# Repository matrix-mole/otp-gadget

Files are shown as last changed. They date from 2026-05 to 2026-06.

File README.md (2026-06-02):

# OTP Gadget

A handheld, air-gapped device for exchanging encrypted messages with a one-time pad. No radio, no network, no cloud. Two devices, one MicroSD card swap, then messages flow by QR code or by hand-typed hex.

## What this repo contains

- **`firmware/`** — MicroPython source running on the gadget.
- **`scripts/`** — flash, build, and dev utilities.
- **`docs/`** — protocol, security, hardware, user-flow, and error-handling specs; parts overview and order checklist with supplier SKUs.
- **`case-design/`** — printable case `.3mf` files, preview images, slicer settings, and the before-print checklist.
- **`assembly/`** — wiring diagrams and assembly notes.

Everything needed to build the gadget end-to-end (source parts, assemble, flash, slice, print, use) is in this repo. Nothing is paywalled.

## Where to go next

| Want to... | Go to |
|---|---|
| Try it in a browser demo | [matrixmole.com/otp-gadget](https://matrixmole.com/otp-gadget) |
| Build one yourself | [Builder docs](https://matrixmole.com/otp-gadget/docs) |
| Reserve a ready-made device (when available) | [Product page](https://matrixmole.com/products/otp-gadget) |
| Read the firmware source | [`firmware/`](firmware/) |
| Support the project | [GitHub Sponsors](https://github.com/sponsors/matrix-mole) |

## Documentation

Deeper design docs for builders and reviewers:

| Topic | Doc |
|---|---|
| Buying guide (parts, SKUs, prices, "do NOT use" notes) | [`docs/order-checklist.md`](docs/order-checklist.md) |
| Chip-level identity for security review | [`docs/parts-overview.md`](docs/parts-overview.md) |
| Hardware spec (GPIO, USB, controls) | [`docs/hardware-spec.md`](docs/hardware-spec.md) |
| Cryptographic protocol (key exchange, wire format, MAC) | [`docs/protocol.md`](docs/protocol.md) |
| Security architecture (KEK/DEK, threat model, weaknesses) | [`docs/security.md`](docs/security.md) |
| User flows (boot, contacts, send/receive, settings) | [`docs/user-flows.md`](docs/user-flows.md) |
| Error handling and recovery | [`docs/error-handling.md`](docs/error-handling.md) |
| Related projects / prior art | [`docs/related-projects.md`](docs/related-projects.md) |

## How it works (short version)

Two devices generate random bytes during setup, XOR them on one card to produce a shared one-time pad, then split that pad so each side's send-bytes match the other side's receive-bytes. Messages are encoded as QR codes on a 3.5" screen and scanned by the receiver. All key material lives on a per-device MicroSD card, encrypted at rest with AES-256-CTR under a PIN-derived key. The hardware has no radio of any kind.

For the full protocol, threat model, and hardware design, see the docs table above (or the [builder docs site](https://matrixmole.com/otp-gadget/docs)).

## Hardware

Off-the-shelf modules, no custom PCB: Waveshare RP2350-Touch-LCD-3.5 (3.5" capacitive touch + RP2350 microcontroller + onboard battery management + onboard TF slot), UART QR scanner, a 3.3 V SPI MicroSD breakout, and a 1.8 Ah LiPo battery. See [`docs/parts-overview.md`](docs/parts-overview.md) and [`docs/order-checklist.md`](docs/order-checklist.md).

## License

- **Firmware** (`firmware/`, `scripts/`, `main.py`): GPLv3 — [LICENSE-firmware](LICENSE-firmware).
- **Documentation and printable case CAD** (`README.md`, `docs/`, `case-design/**` including the `.3mf` files, `assembly/`): CC BY-SA 4.0 — [LICENSE-docs](LICENSE-docs).
- **Matrix Mole / OTP Gadget brand**: not licensed. Forks must not present themselves as the official product.

## Supporting the project

If this is useful to you, you can support the work via [GitHub Sponsors](https://github.com/sponsors/matrix-mole). All revenue goes back into parts, testing, and (eventually) EEA compliance for a built-unit run via the reservation model on the product page above.

## Branching

Two-tier: feature branches → `main`. Never commit directly to `main`.

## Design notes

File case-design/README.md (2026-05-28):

# Case design

3D-printed enclosure for the OTP gadget. Two parts (top and bottom) screwed together, designed in Fusion 360.

## What's in this folder

All files below ship publicly under CC BY-SA 4.0. The project is fully open source - nothing here is paywalled.

- [`README.md`](README.md) - this file.
- [`slicer-settings.md`](slicer-settings.md) - the slicer settings used to print the case. Useful for anyone slicing the supplied `.3mf` files, or designing their own enclosure with similar tolerances.
- [`previews/case-top-preview.png`](previews/case-top-preview.png) - screenshot preview of the top shell.
- [`previews/case-bottom-preview.png`](previews/case-bottom-preview.png) - screenshot preview of the bottom shell.
- [`previews/case-slice-orientation.png`](previews/case-slice-orientation.png) - PrusaSlicer plate/orientation preview.
- `Case bottom.3mf` - printable bottom shell.
- `Case top.3mf` - printable top shell.
- `Case-slice-file.3mf` - pre-arranged slicer project file (a convenience: opens both shells in PrusaSlicer with the orientation/plate layout already set).
- `Case.f3z` - Fusion 360 archive (parametric source). Open this if you want to edit cutouts to fit substituted parts.
- `Case.step` - neutral CAD interchange (STEP). Same model as `Case.f3z`, but openable in FreeCAD, Onshape, SolidWorks, etc. Loses Fusion's parametric history.

## Preview

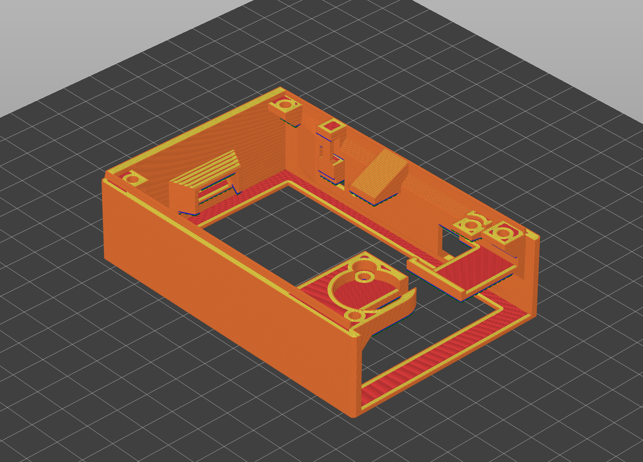
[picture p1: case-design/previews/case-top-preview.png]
Case top preview


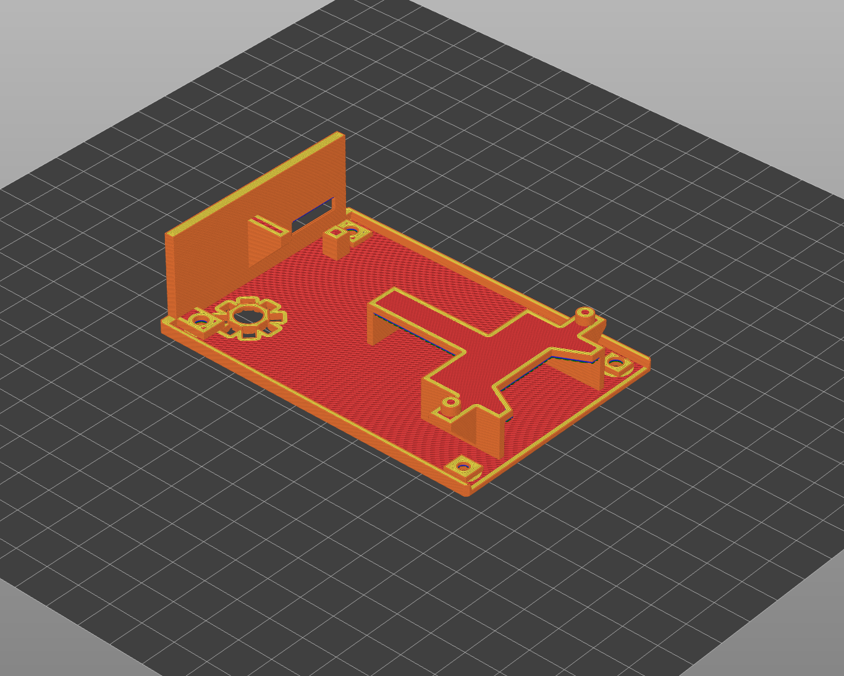
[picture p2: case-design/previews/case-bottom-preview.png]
Case bottom preview


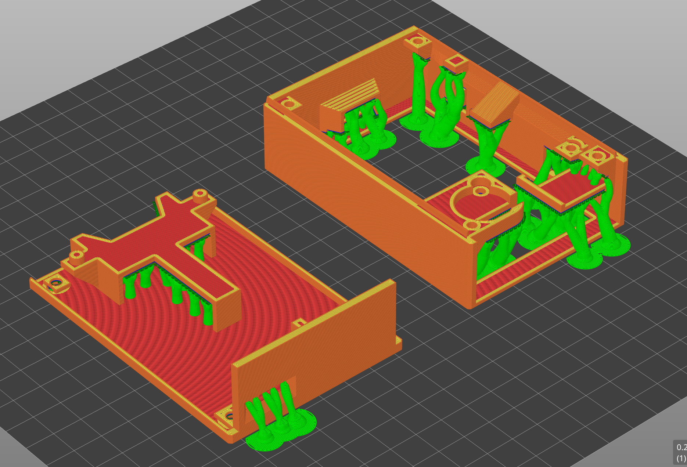
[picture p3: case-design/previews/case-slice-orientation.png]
PrusaSlicer orientation preview


## Want to support the project?

The CAD is free. If it's useful to you, you can chip in via [GitHub Sponsors](https://github.com/sponsors/matrix-mole). Donations help fund parts, testing, and an eventual EEA-compliant built-unit run via the reservation model.

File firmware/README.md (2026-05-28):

# Firmware

Written in **MicroPython**. Deployed to hardware via `scripts/flash.sh` (uses `mpremote`; see [`scripts/README.md`](../scripts/README.md) for usage). Thonny IDE is used only for interactive debugging/REPL.

## First-time board setup (install MicroPython)

> **Do this before assembling the case.** The `BOOTSEL` button is on the bare Waveshare board and is not exposed through the assembled case. If you close the case before flashing MicroPython, you will have to take it apart again.

A fresh Waveshare RP2350-Touch-LCD-3.5 ships with Waveshare's demo firmware (a C program). Before `scripts/flash.sh` can deploy our firmware, MicroPython itself has to be on the board.

1. Download Waveshare's MicroPython build for this exact board:
   <https://github.com/waveshareteam/RP2350-Touch-LCD-3.5/blob/main/firmware/MicroPython/WAVESHARE_RP2350_Touch_LCD_3.5.uf2>
   (On the GitHub page, click the **Download raw file** button.)
2. Press and hold the **`BOOTSEL`** button on the Waveshare board.
3. While still holding `BOOTSEL`, plug the board into your computer with a USB-C **data** cable (charge-only cables will not work).
4. Release `BOOTSEL`. The board now mounts on your computer as a USB drive named `RPI-RP2`.
5. Drag the downloaded `.uf2` file onto the `RPI-RP2` drive. The board reboots into MicroPython automatically; the drive disappears from your file manager.

You only do this once per board. The MicroPython runtime persists across reboots.

After this, MicroPython is on the board but the OTP firmware is not yet — see [`../scripts/README.md`](../scripts/README.md) (the `flash.sh` section) to deploy it.

## Index

- `core/` - pure Python business logic (OTP, SD data structure, message flows). Runs anywhere.
- `hal/` - hardware abstraction layer (see below)
  - `real.py` - real hardware implementation (MicroPython, runs on board)
  - `sim.py` - simulated implementation (runs on laptop)
  - `drivers/` - vendored MicroPython drivers (ST7789, FT6336U, sdcard, AXP2101, PCF85063) bundled with the firmware
- `sim/` - localhost web app simulating the touchscreen UI (Flask)
- `tests/` - unit tests for core logic
- `setup/` - board setup scripts and one-time config
- `main.py` - board entry point: constructs `RealHAL` and calls `main_loop`

## Architecture

All core logic lives in `core/` as plain Python - no hardware calls, no MicroPython-specific code. Hardware is accessed exclusively through the **hardware abstraction layer (HAL)**: a small interface with two implementations, `real.py` and `sim.py`. The core never knows which one it's talking to.

**HAL responsibilities:**
- `get_random_bytes(n)` - TRNG on board, `os.urandom()` in sim
- SD card read/write - real SPI/onboard TF on board, local filesystem in sim
- Display output - real screen on board, served to browser in sim
- Touch input - capacitive touch on board, mouse clicks in browser in sim
- QR scanner input - UART on board, text input or file upload in sim

## HAL Interface

All method signatures that `core/` may call. Both `real.py` and `sim.py` must implement every method exactly.

```python
# Entropy
hal.get_random_bytes(n: int) -> bytes

# Display - portrait 320×480; all rotation handled inside the driver
hal.fill_rect(x: int, y: int, w: int, h: int, color: int) -> None
hal.blit_rect(x: int, y: int, w: int, h: int, buf: bytes) -> None  # buf = RGB565 bytes

# Touch - portrait coords (origin top-left), or None if no touch
hal.get_touch() -> tuple[int, int] | None

# SD cards
hal.mount_card(slot: str) -> str          # slot='own'|'guest'; returns 'MOUNTED'|'NO_CARD'|'WRONG_FS'
hal.unmount_card(slot: str) -> None
hal.read_file(slot: str, path: str) -> bytes          # raises OSError if file missing; whole-file - small files only
hal.write_file(slot: str, path: str, data: bytes) -> None  # atomic: writes .tmp then renames; whole-file - small files only; auto-creates parent dirs
hal.delete_file(slot: str, path: str) -> None
hal.delete_tree(slot: str, path: str) -> None   # recursively delete a directory and all contents
hal.file_exists(slot: str, path: str) -> bool
hal.free_space(slot: str) -> int          # available bytes

# Plaintext streaming (guest-card OTP.bin, X_own.bin - multi-MB, do not fit in RAM)
hal.read_file_stream(slot: str, path: str, offset: int, length: int) -> Iterator[bytes]
hal.write_file_stream(slot: str, path: str) -> WriteHandle  # .write(data), .close(); atomic tmp+rename on close; auto-creates parent dirs

# Secrets key management - call unlock_secrets once after PIN derivation
hal.unlock_secrets(key: bytes) -> None   # stores derived key in RAM
hal.lock_secrets() -> None               # zeroes key from RAM

# Encrypted own-card secrets (AES-256-CTR) - requires unlock_secrets() first
hal.read_secret(path: str) -> bytes                                   # whole-file - small files only
hal.read_secret_slice(path: str, offset: int, length: int) -> bytes  # seeks to offset, decrypts only length bytes
hal.overwrite_secret_slice(path: str, offset: int, data: bytes) -> None  # in-place logical overwrite of decrypted bytes
hal.write_secret(path: str, data: bytes) -> None                      # whole-file; generates fresh IV on every write

# Encrypted streaming for pad files (pad_send.bin / pad_receive.bin - 5 MB each)
hal.read_secret_stream(path: str, offset: int, length: int) -> Iterator[bytes]  # CTR seek + chunked decrypt
hal.write_secret_stream(path: str) -> WriteHandle  # fresh IV at offset 0; .write(data), .close(); atomic tmp+rename

# MCU flash (device_secret, PIN attempt state)
hal.flash_read(path: str) -> bytes        # raises OSError if missing
hal.flash_write(path: str, data: bytes) -> None
hal.flash_exists(path: str) -> bool
hal.flash_delete(path: str) -> None       # no-op if missing; used by full factory reset

# QR scanner
hal.qr_ping() -> bool                    # True if scanner responds to heartbeat
hal.qr_scan() -> str | None              # triggers scan; returns hex string or None on timeout
hal.qr_poll() -> str | None              # non-blocking single check; first call triggers, subsequent calls return result when ready (resets after a value or after >1 s gap to handle re-entry)

# Battery
hal.battery_status() -> tuple[int, bool] # (percent 0–100, is_charging)

# Power management
hal.power_button_pressed() -> bool  # True once if a short press occurred since last call; clears flag on read
hal.power_off() -> None             # zeros DEK from RAM then triggers AXP2101 hardware shutdown; never returns
# Note: inserting a USB-C cable does NOT boot the device. RealHAL.__init__ reads
# PWRON_STATUS (reg 0x20) immediately after AXP init and calls axp.power_off() if
# the VBUS-only flag is set (bit 2) and the button flag is clear (bit 0). The AXP2101
# continues charging the battery; only the MCU powers down. See bring-up checklist #13.
hal.feed_watchdog() -> None         # pets the hardware watchdog; every UI loop must call this once per iteration. No-op in sim.

# Time - monotonic millisecond counter, wraps per MicroPython semantics
hal.ticks_ms() -> int                    # used for auto-lock idle timer and PIN-screen auto-power-off timer

# Wall-clock time from onboard RTC (PCF85063A) - survives power cycles
hal.rtc_now() -> int                     # unix seconds; used for PIN cooldown across reboots
```

**Filesystem note:** `write_file` and `write_file_stream` auto-create any missing parent directories (`/device/`, `/exchange/`, `/secret/`) so card init doesn't need a separate `mkdir` step. Same behavior in sim and on board.

**Time note:** `hal.ticks_ms()` is a monotonic millisecond counter used by core for the auto-lock idle timer and the PIN-screen auto-power-off timer. On board it wraps `time.ticks_ms()`; in sim it wraps `time.monotonic_ns() // 1_000_000`. Core must use `ticks_diff`-style subtraction (mod 2³⁰) and never compare raw values.

**RTC note:** `hal.rtc_now()` returns unix seconds from the onboard PCF85063A RTC, which runs off the LiPo and survives power cycles. Used only for the PIN cooldown, which must persist across reboots (`ticks_ms` resets on boot and cannot tell 10 s from 10 h). In sim it wraps `time.time()`. The RTC is set to a reasonable epoch at first boot; the absolute value doesn't need to be accurate, only monotonic across reboots.

## Screen Flow

The full set of screens and transitions. Source of truth - new screens get added here first.

```
Splash (gray screen + big gray "OTP", ~1.2 s) → Boot

Boot
 ├─ no /flash/device_secret.bin → DeviceSetup → (back to Boot)
 ├─ own card has no /secret/verify.bin → CardInit → (back to Boot)
 ├─ /exchange/ has staging on own card → IncompleteExchange (named after in_flight) → Home
 └─ otherwise → PINEntry

PINEntry → (reconcile_in_flight: silently clear stale markers) → Home
 └─ ? button (upper-right, ~36×36 px) → PINHelp modal  ← also shown on the cooldown screen
       ├─ "Restore using device secret backup" → PickRestoreMethod
       │     ├─ QR scan → verify entered value == /flash/device_secret.bin
       │     │     ├─ match    → SetNewPIN → re-derive KEK → re-wrap DEK → reset attempt counter → Home
       │     │     └─ no match → error: "Device secret does not match" → back to PickRestoreMethod
       │     └─ Manual hex entry (hex keypad) → same verify/branch as QR scan
       └─ "Wipe card & start fresh" → WipeConfirm (type RESET on QWERTY keyboard)
             ├─ cancelled → back to PINEntry
             └─ confirmed → two options:
                   ├─ "Wipe card only"        → delete /secret/ + /exchange/ → CardInit
                   └─ "Full factory reset"    → FactoryResetConfirm (second warning screen)
                         ├─ cancelled → back to WipeConfirm
                         └─ confirmed → delete /secret/ + /exchange/ + MCU flash (device_secret + PIN state) → re-enter main_loop → DeviceSetup

Home (3 buttons + gear icon top-right + lock icon top-left)
 ├─ Lock icon → immediate lock (DEK zeroed, history cleared) → PINEntry
 ├─ Send → ContactPicker → Keyboard → ShowCiphertext (QR + hex) → Home
 ├─ Receive → PickInputMethod
 │             ├─ QRScan → ShowPlaintext (auto-routed via HMAC trial; "From: <name>") → Home
 │             └─ Manual → Keyboard (hex) → ShowPlaintext → Home
 ├─ Contacts (list, created_at order; synthetic pending-add row prepended when in_flight.kind == "add")
 │    ├─ + Add contact → Keyboard (name; uniqueness checked) → set in_flight → exchange route
 │    │     ├─ guest has /exchange/X_own.bin → FinalizeExchange (B-side) → on success: commit + clear in_flight → Contacts
 │    │     └─ else                          → PrepareExchange (A-side; Cancel button aborts: deletes X_own.bin, clears in_flight) → Contacts
 │    │   (+ Add contact disabled while in_flight != null)
 │    ├─ tap Ready row → ContactThread (in-RAM messages with this contact, shown in full and line-wrapped, line-paginated newest-first; cleared on auto-lock)
 │    │     ├─ New message → Keyboard (with this contact) → ShowCiphertext → ContactThread
 │    │     └─ … menu → ContactDetail
 │    ├─ tap non-Ready row (Waiting / Ready to finalize / Re-exchange interrupted / pending add) → ContactDetail
 │    │     (action depends on runtime state - see ContactDetail)
 │    └─ Back → Home
 ├─ ContactDetail (status-driven)
 │    ├─ Ready                 → New message · Re-exchange · Delete contact
 │    ├─ Ready to finalize     → Finalize exchange (commits contact for kind="add"; clears in_flight)
 │    ├─ Waiting / Pending     → (no action; informational)
 │    ├─ Re-exchange interrupted → Restart re-exchange · Delete contact
 │    └─ Pending add (synthetic row) → Finalize exchange (when OTP.bin present) · Discard exchange
 └─ Settings (gear icon, top-right of Home)
      ├─ ChangePIN → Home
      ├─ ViewDeviceSecret → Home
      └─ BurnAfterReading row → ? help modal or toggle → Settings

AutoLock (5 min idle, any screen except DeviceSetup/CardInit) → PINEntry
AutoPowerOff (10 min idle at PINEntry) → device shuts down (AXP2101 power_off)
```

`IncompleteExchangeScreen` (boot-only modal) handles the "user power-cycled mid-exchange" case. Mid-session, the equivalent path is Contacts → tap row → ContactDetail → Finalize/Discard. There is no Home-level modal interrupt.

Battery icon and any active warnings (card status, scanner not detected) overlay on every screen except DeviceSetup, CardInit, and PINEntry.

The gear icon is a small touch target in the top-right of Home (roughly 36×36 px); the lock icon is a matching target in the top-left. Neither is repeated on subscreens - Settings is only reachable from Home; manual lock is only reachable from Home.

`IncompleteExchangeScreen` (the boot-time "Incomplete exchange with \<name>. Finalize or discard?" prompt, triggered when `/exchange/` has leftover staging on own card) reads `in_flight.name` from the manifest. Returns to Home after finalize (which commits the contact for `kind == "add"`) / discard (which clears `in_flight` and wipes staging). From there the user can navigate to Contacts to see the new contact or, if discarded, confirm it didn't land in the list.

## Touch

**Chip:** FT6336U on I2C1 (GPIO34/35 - SDA/SCL), with reset on GPIO24 and the chip's interrupt line on GPIO25 (left unused - see "Polling, not IRQ" below). Vendored driver at `firmware/hal/drivers/ft6336u.py`. The HAL wraps it as `get_touch() -> tuple[int, int] | None`.

**Coordinate mapping:** The FT6336U on this board reports portrait coordinates directly (x in 0..319, y in 0..479) - no rotation is applied in either the driver or the HAL. Verified by the five-target sweep in `check_13_touch_alignment.py`; see bring-up log item 8b.

**Polling, not IRQ:** Each call to `hal.get_touch()` polls the FT6336U over I2C from the main thread (TD_STATUS + the four touch-coordinate bytes). The chip's INT line on GPIO25 is wired but no interrupt handler is attached.

The shared I2C1 bus also carries traffic for the AXP2101 (battery + power-button bit) and the PCF85063 RTC. An older revision attached a hard IRQ to GPIO25 that performed I2C reads from inside the handler; on this bus that race-collided with main-thread I2C transactions to the AXP2101 / RTC and could leave the FT6336U (or the bus itself) wedged. Observed symptoms: touch stops registering, the short-press power-off bit (also polled over I2C in the main loop) is never seen, and the device appears frozen until the user holds PWR for ~5 s to trigger the AXP2101 hardware shutdown. Keeping all I2C access on one thread removes the race entirely. The watchdog (see below) is the second-line defense if anything else hangs.

## Display

**Orientation:** Portrait (320×480).

**Driver:** Start from the ST7789 example in [`docs/waveshare-examples-repo/examples/MicroPython/01_GUI/ST7789.py`](../docs/waveshare-examples-repo/examples/MicroPython/01_GUI/ST7789.py). That file handles init, window selection, single pixel, single square, full-screen fill - enough to boot the screen but not enough for a UI. Extend it with at least `fill_rect(x, y, w, h, color)` and `blit(x, y, w, h, buffer)` so glyphs and the QR matrix can be pushed as rectangular blocks.

**No power-on static:** On power-up the ST7789's internal RAM holds uninitialized garbage. The driver therefore keeps the backlight **off** until after `lcd_init()` *and* a full-screen solid-gray fill have run, then enables the backlight. The device never shows random pixels - it powers on to a solid gray screen (gray, not black, so it is obviously on). The boot flow then shows a brief (~1.2 s) splash: a big gray "OTP" stacked vertically, drawn purely with `fill_rect` block letters (no image assets), then the first real screen. The splash is HAL-agnostic so it renders identically in the simulator.

**Rendering strategy:** Direct-to-SPI. Each draw call pushes pixels straight over SPI; no RAM framebuffer. Pros: tiny memory footprint (a full 320×480×16-bit framebuffer would be ~307 KB out of 520 KB SRAM). Cons: visible flicker on large redraws.

If flicker turns out to be bad in practice, upgrade to a **partial framebuffer**: allocate a small RAM buffer for the region being redrawn (e.g. one keyboard row or the QR area), draw into it, then blit it to the screen in one SPI transfer. No full-screen framebuffer is ever allocated.

**Text input partial updates:** Screens with a text input field must use character-level partial updates - never clear the whole input area on every keypress. The pattern (used in `SendScreen` and `AddContact`):
- **Fast path** (+-1 char, no line reflow): repaint only the 1-2 character slots that changed. The font is monospace so slot positions are `x = left_margin + index * font.max_width()`. For append: draw the new char (and cursor if shown) at their slots - no clearing needed since `draw_text` fills its own background. For delete: clear exactly one vacated slot with `fill_rect`.
- **Slow path** (initial draw, line wrap/unroll, or any other case): compare new vs previously rendered lines and repaint only lines that differ - never the whole area.
- Track rendered state in `prev_lines` / `prev_display` locals in the screen's `draw_input` closure. Reset these when `draw_chrome` wipes the screen.

**Widget layer:** Small custom layer (button, label, keyboard) built on top of the driver primitives. No LVGL or external UI framework, to keep the dependency footprint minimal.

## Fonts

**Tool:** [Peter Hinch's `font_to_py`](https://github.com/peterhinch/micropython-font-to-py) - converts a TTF/BDF to a `.py` file with all glyphs packed as bytes. Run once per size; output files are committed to the repo.

**Font:** DejaVu Sans Mono (monospace - simplifies keyboard layout and hex alignment).

**Two sizes:**
- `font_14.py` - ~14 px tall, used for messages, hex output, labels
- `font_28.py` - ~28 px tall, used for keyboard keys and headings

Both files live in `firmware/core/fonts/`. The widget layer has one primitive, `draw_text(fb, x, y, text, font, color)`, that looks up each glyph and blits pixels into the framebuffer. Works identically in the simulator and on hardware - no HAL dependency.

## QR Code Generation

**Library:** `uQR` - a single pure-Python `.py` file dropped onto the board. Gives a 2D list of booleans (True = black module). The display layer iterates the matrix and draws filled squares onto the framebuffer.

`adafruit_miniqr` was considered but only supports QR versions 1–9, which cannot encode any of our payloads (see `scripts/qr_size_check_results.md`). `uQR` has no such cap.

**Message length cap: 500 bytes of plaintext.** On-board uQR produces a QR v22 (105 modules, ~3.05 px/module on the 320 px screen) - above the 3.0 px/module readability threshold. 600 bytes would drop below 3.0 px/module. One QR frame covers the entire message; no multi-frame scheme. The UI enforces this cap with a character counter during text entry.

**uQR MicroPython patches:** Two changes are needed to make uQR work under MicroPython (see bring-up log item 10 for details):

1. `QRData.write()` for `MODE_ALPHA_NUM` must use 1-byte slices (`chars[0:1]`) instead of integer indexing (`chars[0]`), because MicroPython's `bytes.find()` does not accept `int` arguments. The vendored `firmware/core/vendor/uQR.py` already has this patch applied.
2. Callers must pass `optimize=0` to `qr.add_data()` so uQR's mode auto-detection runs through `optimal_mode()` (a plain membership check) instead of the regex-based `optimal_data_chunks` (which misbehaves under MicroPython's stripped-down `re`). Without this, uQR falls back to `MODE_8BIT_BYTE` and the QR version balloons.

### QR Sizing Spike

Before the cap is frozen in firmware, a one-off measurement script determines the largest plaintext that still produces a QR readable on the 320 px screen. No hardware needed - runs on a laptop in a venv.

**Script:** `scripts/qr_size_check.py` (throwaway, committed so results are reproducible).

**What it does:**

1. For a range of candidate plaintext sizes (200–750 bytes), it builds a realistic frame: `[offset (4)] [length (2)] [ciphertext (N)] [tag (8)]`, hex-encodes it uppercase, and feeds the resulting string to the `qrcode` PyPI library (desktop stand-in for `uQR`).
2. Prints a table with: plaintext size, hex-string length, QR version chosen, module count (N×N), and px-per-module on a 320 px screen (`320 // N`).

**Note:** `uQR` itself is MicroPython-only and was not run on the laptop. Desktop results use `qrcode`, which produces equivalent output. Correctness of `uQR` specifically is verified in bring-up checklist item 10.

**Decision rule:** target **≥3 px per module** on the 320 px screen. Below that, the GM861XS scanner starts struggling at normal hold distance. The largest plaintext size that still hits that threshold (with headroom for ECC level M) becomes the firmware cap.

**Output of the spike:**

- The chosen plaintext cap (written back into this README replacing "TBD").
- Confirmation that `uQR` is the chosen library (already decided - see bring-up checklist item 10 for on-device verification).
- The picked ECC level.
- A short note committed to `scripts/qr_size_check_results.md` so the numbers are auditable later.

## SD Card Driver

**Library:** patched copy of MicroPython's standard `sdcard.py` (the same file Waveshare ships in `examples/MicroPython/02_SD/sdcard.py`). Lives at `docs/waveshare-examples-repo/examples/MicroPython/02_SD/sdcard.py` in this repo with the patches below applied; `real.py` ships this file alongside the firmware.

Wired to the onboard TF slot via SPI1 (`sck=GPIO26, mosi=GPIO27, miso=GPIO28, cs=GPIO31`).

**Patches applied** (see bring-up log item 11 for full debugging trail):

1. **CRC stop-bit fix.** Every SD command frame's last byte must end with bit 0 = 1 (the stop bit). The shipped driver passes `crc=0` (LSB = 0) for every command except CMD0/CMD8. Most cards tolerate this; the Intenso 32 GB SDHC (and other strict cards) silently refuse to respond. All `crc=0` arguments were changed to `crc=0x01` (CRC7 = 0, stop bit set), which keeps CRC checking off while making the frame format-legal.
2. **`_CMD_TIMEOUT` bumped from 100 → 1000.** Some 32 GB cards need >100 polls of ACMD41 before reporting ready (MicroPython issue #7129). Belt-and-suspenders.
3. **Bounded post-write busy-waits.** The stock driver's `write()` and `write_token()` end in unbounded `while spi.read(1)[0] == 0: pass` loops that poll MISO until the card signals "write done". If the card is hot-pulled during a write, MISO floats / reads 0 forever and the MCU spins in that loop - touch dies, the power-button poll dies (also I2C-blocked behind the spinning loop), and only a 5 s long-press recovers. Both loops are now bounded by a **500 ms wall-clock deadline** (`time.ticks_ms`) and raise `OSError(5)` (EIO) on timeout, so a yanked card surfaces as a normal exception instead of a freeze. 500 ms is above the SD spec's worst-case programming time (~250 ms for SDHC), so a healthy but slow card is not falsely cut off; an earlier fixed-poll-count bound was too aggressive for the Intenso 32 GB SDHC and tripped on legitimate writes.

Without these patches, `sdcard.SDCard.__init__` raises `OSError: timeout waiting for v2 card` on this board with this card, and hot-pulling the card during any write hangs the MCU.

### Atomic write hygiene

All file writes (`write_file`, `write_secret`, `write_file_stream`, `write_secret_stream`) use a tmp+rename pattern: data goes to `<final>.tmp` first, then `os.rename` swaps it into place. Two failure modes can leave a stale `.tmp` behind:

1. **Exception mid-write** (e.g. SD read/write timeout, card pulled). The write handle's `__exit__` and the whole-file write helpers now **best-effort delete the `.tmp`** on any exception so the next attempt isn't blocked and FAT doesn't accumulate orphaned clusters. A `try: os.remove(tmp) except OSError: pass` around the cleanup keeps the original exception propagating.
2. **Hard reset mid-write** (watchdog reboot, battery yank, PWR long-press). The MCU is gone before `__exit__` runs, so the `.tmp` survives into the next boot. To self-heal: after `mount_card("own")` succeeds, `RealHAL` sweeps `/secret/` and `/exchange/` for any `*.tmp` files and removes them. The sweep is shallow (only those two directories - and `/secret/contacts/<id>/` for per-contact bookkeeping `.tmp`s) and runs once per mount, so the cost is a couple of directory listings.

Together these guarantee that no atomic write leaves persistent state behind, even across crashes, and FAT clusters cannot leak into permanent orphans the way they did on the Intenso card during early bring-up.

## Message Authentication

Each message carries an 8-byte HMAC-SHA256 tag. It replaces CRC16 - it catches both accidental corruption (scan errors, typos) and deliberate tampering, since forging a valid tag requires 8 secret pad bytes the attacker doesn't have.

**Algorithm:** HMAC-SHA256, truncated to 8 bytes. Applied over `offset || length || ciphertext` before hex-encoding.

**Key:** `pad_send[offset+length : offset+length+8]` on the sender side; `pad_receive[offset+length : offset+length+8]` on the receiver side. These bytes are consumed alongside the ciphertext - the watermark advances by `len(plaintext) + 8`.

On mismatch the UI shows "Message authentication failed" and does not decode.

## QR Scanner Configuration

Two scanner settings differ from factory defaults and are required for the firmware to work:

| Setting | Zone bit | Bits to set | Required value | Factory default |
|---|---|---|---|---|
| Read mode | `0x0000` | bits 1-0 | `01` (Command Triggered) | `00` (Manual) |
| Tail type | `0x0060` | bits 6-5 | `01` (CRLF) | `00` (CR) |
| Allow tail | `0x0060` | bit 0 | `1` (on) | `1` (on) |

Source: GM861XS User Manual §10.6 zone-bit list (read mode) and §7.6 (tail). All other defaults (baud 9600, parity none, QR Code on, prefix/AIM/Code ID off) are already correct.

**Auto-config on boot:** the MCU configures the scanner over the same UART used for scanning, using the zone-bit protocol in the GM861XS user manual §10. No manual scanning of setup QR codes is needed. On every boot, after `qr_ping` confirms the scanner is alive:

1. Read zone `0x0000`. Mask in bits 1-0 = `01` to compute the target byte (preserving bits 7-2, which control LED, mute, and lighting).
2. Read zone `0x0060`. Mask bits 6-5 = `01` and bit 0 = `1` to compute the target byte.
3. For each zone whose current value differs from its target, write the target (zone-bit write command, type `0x08`).
4. If anything was written, send the "save to flash" command (`7E 00 09 01 00 00 00 DE C8`, 9 bytes, fixed CRC).
5. If both zones already match, do nothing - no flash writes.

A fresh-from-factory scanner self-configures on first boot. Settings persist in the scanner's internal flash, so step 4 normally runs only once per device. Subsequent boots pay two reads (~50 ms) and exit. If `qr_ping` fails (scanner unplugged or unreachable), auto-config is skipped and the UI shows the existing "QR scanner not detected" warning; next boot retries.

**Why command-triggered:** the firmware sends a trigger byte over UART when the user enters the scan screen; the scanner reads once, sends the result, then goes idle. Continuous mode would spam UART non-stop.

**Tail delimiter:** firmware reads UART bytes until `\r\n` to know the scan result is complete.

**Heartbeat:** at runtime, firmware pings the scanner with `7E 00 0A 01 00 00 00 30 1A` and expects `03 00 00 01 00 33 31` back (manual §2.1.2). If no response within timeout, QR scanning is disabled and the UI shows a warning.

**CRC:** zone-bit read/write commands use CRC-CCITT (poly `0x1021`, **initial value `0`**, no reflection, no xor-out) computed over the Types+Lens+Address+Datas bytes. The save and heartbeat commands have fixed CRCs documented in the manual, so only the runtime reads/writes need an on-board CRC computation.

**Frame formats** (manual §10.2, §10.3):
- Read: `7E 00 07 01 [ADDR_H] [ADDR_L] 01 [CRC_H] [CRC_L]` (9 bytes; trailing `01` = number of zones)
- Read response: `02 00 00 01 [VALUE] [CRC_H] [CRC_L]` (7 bytes)
- Write: `7E 00 08 01 [ADDR_H] [ADDR_L] [VALUE] [CRC_H] [CRC_L]` (9 bytes)
- Write response: `02 00 00 01 00 33 31` (7 bytes, fixed)

## Watchdog

A hardware watchdog (`machine.WDT(timeout=8000)`) is wired into `RealHAL` and is meant to be fed at least once every 8 seconds. Every UI loop that polls touch / power button (Home, PIN entry, Send, Receive, Contacts, Exchange progress, all "tap to continue" wait screens, etc.) calls `hal.feed_watchdog()` once per iteration, right next to the existing `hal.power_button_pressed()` / `session.is_idle_expired()` checks. The long-running streaming inner loops in `exchange.py` already check power button + idle on a chunk-modulo schedule; the watchdog feed is added to the same schedule (not every chunk, to keep overhead negligible).

This is a backstop, not a primary defense: any loop that fails to feed it is treated as a bug to be fixed. The watchdog exists so that an unanticipated hang produces an 8 s automatic reboot instead of the user having to hold PWR for ~5 s to trigger the AXP2101 hardware long-press shutdown (still available as the absolute last resort, per the root README's "Physical Controls" section).

`SimHAL.feed_watchdog()` is a no-op - there is no equivalent hardware watchdog on the laptop, and a soft-hang in sim is preferred to be investigated manually.

Enabled per device via `/flash/watchdog.txt`. Toggle with `scripts/inspect.sh <label> watchdog-on|off`. Production builds must ship with the file present on `/flash/`. When debugging with REPL open, use `watchdog-off` so the WDT does not reboot the board while you are inspecting state.

## Debug Tooling

Post-freeze debugging uses three pieces: a **breadcrumb** (last-known state), **touch injection** (host-driven synthetic taps), and an **inspect script** (`scripts/inspect.sh`).

**Agent-friendly:** with the gadget plugged in via USB-C, an AI assistant can drive the full debug loop on its own - flash, enable debug mode, inject touches, read post-freeze state - using `scripts/inspect.sh list` + `scripts/flash.sh --label <name>` + the `inspect.sh` verbs. See `scripts/README.md` for the workflow.

### Breadcrumb (`/flash/last_state.txt`, `/flash/breadcrumb_ring.txt`)

`firmware/core/breadcrumb.py` records every screen and phase transition in two files:

- `/flash/last_state.txt` is **overwritten** on every `mark()` with a single line. Used by `inspect.sh state` for the "live state" responsiveness check.
- `/flash/breadcrumb_ring.txt` is **appended** on every `mark()`. Rotated to `.prev` when it exceeds ~4 KB. Captures the trail of recent transitions so a crash site is not overwritten by post-reboot screens.

Both files share the same line format:

```
<unix_seconds> <ticks_ms> <free_ram_bytes> <label>
```

Example:
```
1746998312 1234567 387424 PrepareExchange.write_X_own@4194304/10485760
```

Label convention: `<Screen>.<phase>` plus optional `@<progress>/<total>` for long-running operations. Streaming loops (exchange.py) update the label on the same modulo schedule used for progress redraws - flash writes are bounded to ~20 per phase, not per chunk.

A third file, `/flash/reboot_history.txt`, is **appended** once per boot with one line: `<unix_seconds> <reset_cause_int> <reset_cause_name>`. Rotated to `.prev` when it exceeds ~4 KB.

### Touch injection

Gated by `/flash/debug_mode.txt`. When absent (production), `get_touch()` is unchanged. When present, `get_touch()` checks `/flash/inject_queue.txt` first: one `x,y` per line; the top entry is consumed and returned as a synthetic touch.

File-based injection was chosen over `mpremote exec`-based injection because exec sends Ctrl-C to acquire a REPL prompt, which raises `KeyboardInterrupt` in the running main loop - unacceptable during in-flight operations. File polling has no such side-effect; the per-touch cost is one flash stat call (no read unless entries are present). `debug_mode` is read once at boot into `self._debug_mode: bool` so the production overhead is a single boolean check.

### Flags

| File | Meaning |
|---|---|
| `/flash/debug_mode.txt` | Enable touch injection via file queue. Absent = production. |
| `/flash/watchdog.txt` | Enable hardware WDT (8 s). Absent = WDT off. |

Both flags are toggled via `scripts/inspect.sh <label> enable-debug|disable-debug` and `watchdog-on|off`, which write/delete the file and reboot the board.

### Production vs debug

Production: both files present (WDT on, touch injection off). Debug session: WDT on, debug mode on (inject taps without disabling the WDT). Temporarily disable WDT only when holding REPL open to inspect a freeze.

See [`scripts/inspect.sh`](../scripts/inspect.sh) for the full set of verbs.

## Hardware Detection on Boot

On startup, the firmware pings each external module and reports any that are unreachable:

- **QR scanner:** sends a ping command over UART and waits for a response. If no response within timeout → UI shows "QR scanner not detected". Scanning is disabled but all other flows work.
- **Guest SD slot:** a disconnected module is indistinguishable from "no card inserted" in software - both fail to mount the same way. Reported as `NO_CARD`.
- **Own SD slot:** onboard and not physically disconnectable.

## SD Card Detection and Validation

Every time a card is mounted (own or guest), a validation step runs before any operation. It returns a status that the UI maps to a plain-language message or warning:

| Status | Meaning |
|---|---|
| `OK` | Card mounted, structure valid, pad material available |
| `EMPTY` | Card mounted but no pad data found |
| `EXHAUSTED` | Card mounted, correctly formatted, but all segments used |
| `FULL` | Card mounted but no space left to write new data |
| `BAD_STRUCTURE` | Card mounted but expected folders/files are missing or wrong |
| `CORRUPTED` | Pad file exists but is truncated or unreadable |
| `WRONG_FS` | Card not FAT32 (e.g. exFAT, NTFS) - fails to mount |
| `NO_CARD` | No card detected |

This logic lives in `core/` - no hardware dependency. The HAL provides the raw mount attempt; core interprets the result.

**UI behavior:**
- Own card missing/invalid on boot → persistent warning banner on every screen, most actions blocked
- Guest card missing/invalid when key exchange is started → error shown, flow blocked
- Any card removed mid-operation → alert shown, operation aborted safely

**Key exchange edge cases:**

| Condition | Shown to user |
|---|---|
| Guest card has no `/exchange/X_own.bin` | "Other party hasn't prepared exchange yet" |
| Guest card has < 10 MB free | "Guest card has no space for exchange" |
| OTP checksum mismatch when A finalizes | "Exchange data corrupted - redo exchange" |
| Incomplete exchange found on own card at boot | "Incomplete exchange found. Finalize or discard?" |
| Own card already has pad data (re-exchange) | Confirmation required: "This replaces existing OTP. Continue?" |

**Implementation note - streaming, not whole-blob:** The 10 MB OTP does not fit in RAM (RP2350 SRAM is ~520 KB). Core uses the streaming HAL methods (`read_file_stream` / `write_file_stream` for plaintext guest-card files; `read_secret_stream` / `write_secret_stream` for encrypted own-card pad files) and never materializes a full pad in memory:

- **B's side (generating):** loop over `X_A` in small chunks (e.g. 4 KB) via `read_file_stream`, generate a same-size chunk of `X_B` from the TRNG, XOR, append to `OTP.bin` via `write_file_stream`, feed the result into a running SHA-256. After the loop, write the final digest into `OTP.bin`'s header. A second streaming pass reads `OTP.bin` back in chunks and writes B's own `/secret/pad_send.bin` and `/secret/pad_receive.bin` via `write_secret_stream` (fresh IV per file; CTR encrypts on the way out).
- **A's side (finalizing):** streaming SHA-256 over `OTP.bin` via `read_file_stream` to verify the checksum, then a second chunked pass to split and encrypt into A's own `/secret/` via `write_secret_stream`.

The same streaming pattern applies if pad size is ever raised beyond 10 MB.

## SD Card Encryption

All files under `/secret/` are encrypted with **AES-256-CTR** using a two-key (KEK/DEK) design: a random **master key (DEK)** encrypts all data; a PIN-derived **wrapping key (KEK)** encrypts only the master key. Changing the PIN re-wraps the tiny master key blob - the pad files are never re-encrypted.

**Key hierarchy:**
```
KEK = PBKDF2_HMAC_SHA256(PIN + device_secret, salt=card_salt, iterations=TUNED)
DEK = 32 random bytes, generated once at card init
      stored as /secret/master_key.enc = AES-256-CTR(key=KEK, plaintext=DEK)
```

On every boot: enter PIN → derive KEK → decrypt `master_key.enc` → get DEK → use DEK for all `/secret/` reads and writes.

Changing the PIN: derive the new KEK, re-encrypt DEK, write new `master_key.enc`. Pad files untouched.

**AES library:** Uses MicroPython's built-in `cryptolib.aes`. CTR mode (mode 6) is **not available** in this MicroPython build - `cryptolib.aes(b'\x00'*32, 6, b'\x00'*16)` raises `ValueError: mode`. ECB mode (mode 1) is available and used to implement CTR manually: for each block, the keystream is `AES-ECB(DEK, IV + block_index)`, XORed with the ciphertext. See `firmware/setup/rp2350-bringup-log.md`.

**AES-CTR helper:** The manual ECB-CTR construction lives in `firmware/core/crypto/ctr.py`. It exposes `aes_ctr_xor(key, iv, data, block_index=0)` for single-shot encrypt/decrypt and `CTRStream(key, iv, start_block_index)` for incremental streaming. Both `master_key.py` (DEK wrap/unwrap) and `real.py` (`read_secret*`/`write_secret*`) use these helpers.

**Bulk ECB optimisation:** `CTRStream` uses a **bulk ECB** approach to avoid the 24 KB/s per-block bottleneck. Rather than calling `aes.encrypt()` once per 16-byte block (65 536 Python→C round-trips per MB), `update()` builds all counter blocks for the incoming chunk into a single bytearray and calls `self._cipher.encrypt(buf)` once. MicroPython's `cryptolib` C source loops over all blocks internally in one Python→C transition, yielding **111 KB/s** (4.6× improvement). The cipher object is cached on the `CTRStream` instance for the stream's lifetime. This makes the composite read+AES+write throughput SD-read-limited (83 KB/s) rather than AES-limited (24 KB/s). See `plans/exchange-speed-improvements.md` Fix 6 for full analysis.

**Iteration count:** MicroPython has no built-in PBKDF2, so it runs as a pure-Python loop around `hashlib.sha256`. Measured throughput on RP2350 (MicroPython v1.28.0) is **~603 iterations/sec**. Default = **1000 iterations** (~1.66 s). Stock desktop-scale values (100 000+) would make boot unusably slow.

**Iteration count is stored per card**, not hardcoded in firmware, at `/device/kdf_params.json` (plaintext - it carries no secret information). Written once when the card is initialized; read on every unlock. If a future firmware raises the default (e.g. faster RP2350 variant, or larger pad sizes needing more resistance), new cards pick up the new value while existing cards keep decrypting with their original value. Without this, bumping the iteration count would silently brick every card ever initialized.

Lower iteration counts are acceptable here because the password already includes `device_secret` (256 random bits from MCU flash). PBKDF2 stretching only matters in the "both device and card stolen" case; against a 4–6 digit PIN, even a few thousand iterations per guess makes offline brute force infeasible on small hardware.

- **device_secret:** stored in `/flash/device_secret.bin` in the MicroPython filesystem on MCU flash. Generated on first boot; never written to the SD card.
- **card_salt:** stored plaintext in `/device/card_salt.bin`. Different per card, so a stolen card is useless on a different device even with the PIN.

**Wrong-PIN detection (`verify.bin`):**
Because the cipher has no built-in way to say "wrong key," there must be a known plaintext to check against. On card init we write `/secret/verify.bin` containing a fixed magic header (e.g. `OTPG_V1`) followed by the `card_salt` echoed back - encrypted with the DEK. On every unlock:

1. Derive KEK from the entered PIN + device_secret + card_salt.
2. Decrypt `master_key.enc` to get the candidate DEK.
3. Decrypt `verify.bin` with the candidate DEK.
4. If the magic header and salt echo match → PIN correct; proceed.
5. If not → PIN (or device_secret) wrong; increment the attempt counter and reject without touching any other `/secret/` file.

This is also how the "Restore device_secret" flow knows whether the pasted backup is correct: run the same check; garbage plaintext means the user entered the wrong value.

**PIN entry and rate-limiting:**
- 4–6 digit PIN entered via touchscreen on every boot.
- After 5 consecutive wrong attempts, cooldown doubles with each further failure (10 s, 20 s, 40 s, …). No wipe.
- Attempt counter and `cooldown_until` (unix seconds from `hal.rtc_now()`) are persisted to MCU flash (alongside `device_secret`), **updated before verification**, not after. A power-cycle between attempts does not reset the counter, and the cooldown is enforced against wall-clock time - not boot-relative `ticks_ms` - so rebooting does not shortcut the wait.

**PIN recovery (? button, upper-right of PIN screen):**
- **Restore using device secret backup:** user provides their saved device_secret via QR scan or manual hex entry. The device compares the entered value against `/flash/device_secret.bin`. On match, the DEK is recovered from `recovery_token.enc` (see below), the user sets a new PIN, a new KEK is derived, and `master_key.enc` is re-written with the DEK re-wrapped under the new KEK. `recovery_token.enc` is also rewritten with a fresh IV (DEK and recovery key unchanged). Pad files, contacts, and all other `/secret/` files are untouched. The attempt counter and cooldown are cleared. As a sanity check, the recovered DEK is used to decrypt `verify.bin` before the new PIN is accepted; a mismatch aborts the restore.
- **Wipe card & start fresh:** after double-confirmation (user types `RESET` on the QWERTY keyboard), the device deletes `/secret/` and `/exchange/` from the own card and re-enters the CardInit flow. All pad data and contacts are permanently destroyed.

**`recovery_token.enc`:** a second wrapping of the DEK kept on the card so the restore flow can recover it without the old PIN.

```
recovery_key       = HMAC-SHA256(device_secret, b"RECOVERY")   ← deterministic from device_secret
recovery_token.enc = [IV (16 bytes)] [AES-256-CTR(recovery_key, DEK)]
```

Written at CardInit, rewritten on every Change PIN and on every successful Restore (always with a fresh IV). Security is unchanged: an attacker can only unwrap `recovery_token.enc` if they have `device_secret` from MCU flash, which already collapses the "device stolen alone" defense - the same threat that PIN+PBKDF2 was protecting against in the first place. In return, restore needs no PIN brute-force loop.

**Device setup flow** (runs once per device, when `/flash/device_secret.bin` is missing):
0. Firmware checks for `/flash/device_secret.bin`. Present → skip to card init check. Missing → device setup (continue below).
1. Device generates `device_secret` and writes it to `/flash/device_secret.bin`.
2. Device displays `device_secret` as a QR code and as hex. Two options are shown:
   - **"I've saved it"** - user types the last 8 hex characters back in; on match the screen dismisses.
   - **"Skip for now"** - proceeds immediately without confirmation (backup not verified).
   This screen is shown only once.
3. Proceed to card init check.

**Card init flow** (runs whenever a mounted own card has no `/secret/verify.bin` - covers both the first card and any later replacement card):
1. UI prompts: "Blank card detected. Initialize?" with `Initialize` / `Cancel`. Cancel returns to home with the card flagged unusable.
2. User sets their PIN (4–6 digits).
3. Device generates `card_salt` (32 random bytes) → `/device/card_salt.bin`.
4. Device generates a random DEK, derives the KEK from `PIN + device_secret + card_salt`, writes `/secret/master_key.enc`, writes `/secret/recovery_token.enc` (DEK wrapped under the device_secret-derived recovery key - see PIN recovery), writes `/device/kdf_params.json` with the tuned iteration count, and writes `/secret/verify.bin`.
5. Card now has no pad data - UI directs user to `Contacts` → `+ Add contact` to populate it.

**Normal boot:** if both `/flash/device_secret.bin` and `/secret/verify.bin` exist → go straight to PIN entry.

**Restore after reflash:** A "Restore device_secret" option in the setup menu accepts the QR or hex backup and rewrites the MCU flash file.

**Key flow:** Core derives the KEK via PBKDF2, decrypts `master_key.enc` to obtain the DEK, then calls `hal.unlock_secrets(dek)`. HAL stores the DEK in RAM and uses it for all subsequent `read_secret`/`write_secret` calls. `hal.lock_secrets()` zeroes it. The sim receives the same call with a deterministic DEK derived from a fixed test PIN - no special-casing needed.

**HAL contract:** `hal.read_secret(path)` and `hal.write_secret(path, data)` wrap all `/secret/` access with AES-256-CTR using the in-RAM DEK. On every write, a fresh 16-byte random IV is generated and prepended to the ciphertext - so the file on disk is `[IV (16 bytes)] [ciphertext]`. On read, the first 16 bytes are peeled off and used as the IV. This ensures every write uses a different keystream, even for files that are rewritten repeatedly (e.g. the watermark).

**Random access into encrypted pads:** Sending or receiving a message only needs a small slice (500 pad bytes + 8 MAC bytes) out of 5 MB `pad_send.bin` / `pad_receive.bin`. Decrypting the full file for every message is not acceptable. CTR mode supports arbitrary-block seek by construction: keystream block N is `AES(DEK, IV + N)`, independent of all other blocks. The HAL exposes `hal.read_secret_slice(path, offset, length) -> bytes` that seeks to the right block and decrypts only the needed range. Since native CTR is not available on the RP2350 build, the keystream is computed manually via AES-ECB: `keystream_block_N = AES-ECB(DEK, IV + N)`, then XORed with the ciphertext slice.

**Random access overwrite for pad scrubbing:** `hal.overwrite_secret_slice(path, offset, data)` updates a small decrypted range inside an encrypted secret file without rewriting the whole 5 MB pad. The HAL reads the file IV, computes the CTR keystream for the requested offset, XORs `data` with that keystream, and writes the resulting ciphertext bytes in place. This is used only for pad scrubbing after successful message authentication. It is a logical overwrite through the SD filesystem, not a forensic-secure physical erase guarantee on MicroSD.

## User Settings

User settings live in encrypted `/secret/settings.json`. Missing file means defaults.

```json
{"burn_after_reading": false, "burn_after_reading_help_seen": false}
```

**Burn after reading:** toggle in Settings, default off. When enabled, a newly decoded received message is displayed once, not added to `session.message_history`, and the used receive-pad range (`offset` through `offset + length + 8`) is scrubbed with random bytes after successful authentication. Replayed messages are not scrubbed again; if the original receive-pad bytes were already scrubbed, replay authentication fails normally.

Boolean settings are rendered as rows with the label on the left, a small `?` help button near the right edge, and a toggle/checkbox at the far right. Tapping the row toggle immediately writes the encrypted settings file. If no modal was shown, only the toggle area is repainted. Tapping `?` opens the standard green-outline modal with the setting name, a short explanation, and `Done`; when it closes, the Settings screen is redrawn because the modal covered the page. The first time `Burn after reading` is enabled, that help modal is shown before the setting is saved so the user sees the MicroSD deletion caveat.

## Bookkeeping File Format

Pad consumption state is stored per contact under `/secret/contacts/<id>/` on the own SD card. Both files are AES-256-CTR encrypted like everything else under `/secret/`.

**`/secret/contacts/<id>/pad_send_watermark.txt`** - plain ASCII integer, e.g. `1234567`. The next unused byte offset in this contact's send pad. Sending a message to this contact advances it by `len(plaintext) + 8` (ciphertext + MAC key).

**`/secret/contacts/<id>/pad_receive_used_ranges.json`** - JSON array of `[start, end]` pairs, e.g. `[[0, 120], [500, 680]]`. Each decoded message from this contact appends its range. Adjacent or overlapping ranges are merged on every write to keep the file small.

**`/secret/contacts.json`** - manifest of all contacts on this card (schema version, `in_flight` exchange marker, contact array `{id, name, created_at}`). See the SD Card Data Structure section in the root README for the full schema.

**Atomic write strategy:** all writes go to `<file>.tmp` first, then `os.rename()` replaces the original. `os.rename()` on FAT32 is a single directory-entry update - if power is lost mid-write, the original file is untouched.

**State mutation order:**
- **Send:** advance the watermark first, then render and show the QR code. If power is lost after the watermark advances but before the QR is shown, those pad bytes are wasted but never reused - safe.
- **Receive, Burn after reading off:** append the used range first, then display the plaintext and add it to in-RAM history. Same principle.
- **Receive, Burn after reading on:** after successful authentication, append the used range, scrub the used receive-pad bytes, then display the plaintext once without adding it to in-RAM history. If the scrub write fails, fail loudly and do not render the plaintext.

## Replay Handling

If a received message's `(offset, length)` range overlaps a range already in `used_ranges`, the device decodes and displays the message normally but shows a warning banner: *"This message has already been decoded."* The user sees the content; no new range is written. If Burn after reading was enabled when the message was first read, the scrubbed pad bytes normally make later replay authentication fail before this warning can be shown.

## Battery Level

The onboard AXP2101 power management chip exposes battery state over I2C. The HAL reads this and provides two values to core: `battery_percent` (0–100) and `is_charging` (bool). The UI displays a battery icon in the corner of every screen, with a charging indicator when plugged in.

In the simulator, battery level is set via a slider and the charger state via a toggle in the hardware panel.

## On-Screen Keyboard

Text input uses one of **three on-screen keyboards**, picked per screen by the kind of input expected. Smaller alphabets get bigger touch targets - important on a 320 px wide screen.

Two widgets back the three variants:

- `Keyboard` - full QWERTY (existing).
- `Keypad` - shared grid widget, parameterized by a layout config (rows × cols, key labels, function row). Used for the digit and hex variants.

All three sit at the bottom of the screen and emit the same callbacks (`on_char`, `on_backspace`, `on_done`) so screens are agnostic to which one they hosted.

**Press feedback:** Every key (character and function) shows a light-blue highlight while held. Only the single pressed key is repainted (not the whole keyboard) - a full repaint would be too slow on direct-to-SPI rendering. The highlight clears when the finger lifts, after the same 150 ms idle window used for hold-debounce.

Both widgets expose one entry point: `update(touch)` where `touch` is `(x, y)` or `None`. Hosting screens call `kb.update(t)` once per loop iteration regardless of touch state; the widget owns all timing (highlight, hold-debounce, layer state, backspace repeat).

### QWERTY keyboard

iPhone-style QWERTY with three layers:

- **Letters** (default): QWERTY, shift key toggles upper/lower case.
- **Numbers & basic punctuation** (`123` key): digits + common punctuation.
- **Symbols** (`#+=` key, reached from the numbers layer): remaining symbols.

Behavior matches iOS: auto-reset of shift after one uppercase letter, `123`/`ABC` layer toggle. Character keys: holding registers exactly once (no repeat). Backspace: holding fires once immediately, then after 400 ms fires repeatedly every 80 ms (standard typematic). Long-press for accented chars is not required for v1.

Used by: message body (Send), contact name (Add contact).

### Digit keypad

iPhone-style 3×3 digit grid plus a function row. Five rows total.

```
┌─────────┬─────────┬─────────┐
│    1    │    2    │    3    │
├─────────┼─────────┼─────────┤
│    4    │    5    │    6    │
├─────────┼─────────┼─────────┤
│    7    │    8    │    9    │
├─────────┼─────────┼─────────┤
│         │    0    │         │
├─────────┴┬────────┴────────┤
│    <     │       GO        │
└──────────┴─────────────────┘
```

Only digits are emitted; there is no way to type non-digit chars. Backspace removes the last digit; GO submits.

Used by: PIN entry (boot unlock), Set PIN (card init), Change PIN (settings).

### Hex keypad

4×4 grid covering `0–9 A–F` plus a function row. Five rows total.

```
┌───────┬───────┬───────┬───────┐
│   0   │   1   │   2   │   3   │
├───────┼───────┼───────┼───────┤
│   4   │   5   │   6   │   7   │
├───────┼───────┼───────┼───────┤
│   8   │   9   │   A   │   B   │
├───────┼───────┼───────┼───────┤
│   C   │   D   │   E   │   F   │
├───────┴┬──────┴───────┴───────┤
│   <    │         GO           │
└────────┴──────────────────────┘
```

Uppercase only (the wire format is uppercase hex - see "Wire Format" in the root README). No way to type non-hex characters.

Used by: device-secret backup confirm (DeviceSetup, last 8 hex chars), manual ciphertext entry (Receive).

### Sim parity

All three keyboards are pixels drawn by core widget code - same in sim and on board. No HTML, no DOM. Per the simulator's fidelity rule, anything inside the 320×480 box is painted by the same Python that runs on hardware.

## Simulator

A small Flask web app (`sim/`) renders a 320×480 touchscreen in the browser. Mouse clicks act as touch input. Runs the real `core/` logic on the backend via `sim.py`. Lets you develop and test the full UI and all flows without physical hardware.

**Layout:**

```
                    [ Power bar ]
[ Hardware panel ]  [ 320×480 screen ]  [ QR input panel ]
```

- **Left panel (hardware):** own SD card slot, guest SD card slot, charger toggle, battery % slider. Both slots have identical UI (see SD Card Slots below). The PIN is entered on the simulated screen exactly as on hardware - no bypass; the real PBKDF2 / `verify.bin` / `master_key.enc` path runs in sim.
- **Power bar (above the screen):** power state label + power on/off button (see Power on/off below).
- **Center:** the simulated touchscreen (portrait, 320×480)
- **Right panel:** QR scanner input field + submit button

Toggling an SD card simulates inserting or ejecting it mid-session. Toggling the charger updates the battery icon. Submitting a QR value injects it as if the physical scanner read it.

**Power on/off (sim-only):** Each instance starts **powered off**. While off, the power bar shows "Device powered off" with a "Power on" button, and the canvas is black - the core thread does not exist. Clicking "Power on" creates a fresh `SimHAL` and starts `main_loop` in a new daemon thread; the boot flow runs from the top. When on, the bar shows "Device powered on" with a "Power off" button; clicking it drops the HAL + thread reference (daemon thread exits naturally) and clears the canvas. Power state lives server-side in the instance registry and is shared across tabs of the same instance; a Flask restart returns every instance to off. No equivalent on real hardware - the physical PWR button cuts power directly. This simulation exists so RAM-clear-on-power-off behavior can be observed in sim. The power control lives in the sim layer (`firmware/sim/app.py`); no code in `core/` or `hal/` is aware of it.

**Fidelity rule:** everything inside the 320×480 box is pixels only, drawn by the exact same widget and font code that runs on the board. No HTML buttons, no CSS text, no DOM keyboard inside the screen area - if core calls `fill_rect` / `blit_rect`, that is all the browser receives. The keyboard, text, and QR matrix seen in the sim are all painted by Python code identical to what will run on hardware.

Panels outside the screen (SD toggles, PIN, QR input, battery slider) are plain HTML/JS - they simulate the physical world around the device, not the screen, so they have no hardware equivalent to preserve.

**Display transport:** a single `<canvas width=320 height=480>` in the center. `sim.py` pushes HAL draw ops over a WebSocket:

- `{op: "fill", x, y, w, h, color}` → `ctx.fillRect`
- `{op: "blit", x, y, w, h, data: <base64 RGB565>}` → decoded into `ImageData` and drawn with `putImageData`

Touch goes back on the same socket: canvas `pointerdown` → `{x, y}` → `hal.get_touch()` returns it to core. The hardware panel uses normal Flask routes to flip flags in `sim.py` (SD mount state, charger, battery %, injected QR strings).

**Crypto parity:** `sim.py` runs real AES-256-CTR against a local folder for `/secret/` - same `read_secret` / `write_secret` / `read_secret_slice` / `read_secret_stream` / `write_secret_stream` semantics as the board, including the per-write random IV and the seek-to-counter math used for random-access pad slicing and streaming. The full PBKDF2 / KEK / DEK / `verify.bin` path runs unchanged in sim - the user enters a real PIN on the simulated screen, and the exact same crypto calls fire as on hardware. This means the first time the seek logic and the unlock flow run for real is not on the board.

### Multi-Instance Hub

Key exchange in the real world involves two physical devices swapping one SD card. The sim models this with a **hub** - a single Flask process that runs any number of device instances side by side. All instances live in one process; there are no separate ports.

**Launch:**

```bash
python -m firmware.sim
```

Opens `http://localhost:8080` - the hub page.

**Hub UI:**
- Device type cards across the top (only "3.5-inch gadget" for now).
- Instance list below: each row shows the instance name, a power-state dot (green = on, gray = off), a "Connect" button that opens the device's sim UI in a new browser tab, a "Rename" button (inline edit, updates `instances.json`), and a "Delete" button (removes from registry; state dir on disk is preserved so it can be re-added or inspected manually).
- "New instance" button → enter a name (must be non-empty) → instance is created (powered off) and its tab opens automatically.

**Power state on the hub:** all instances start powered off after a Flask restart. The dot refreshes when the page loads; toggling power from an instance tab is reflected the next time the hub page is refreshed (no live push - keeps the hub trivial).

**Sim state lives under `sim_state/`:**
```
sim_state/
  instances.json        ← instance registry (auto-created; empty list if missing)
  cards.json            ← global SD-card registry (auto-created; empty list if missing)
  alice/
    mcu_flash/          ← simulated MCU flash (device_secret.bin, PIN state)
  bob/
    mcu_flash/
  cards/
    <card_id>/
      device/           ← simulated SD card (/device/, /exchange/, /secret/)
      exchange/
      secret/
```

SD cards are **global**, like instances - they exist independently of any device and can be mounted into any slot of any instance. Per-instance state holds only `mcu_flash/` (the MCU's internal flash, which is per-device by definition) plus the `slots` field in `instances.json` (which card is currently in own / guest, persisted across power cycles).

If `instances.json` or `cards.json` is missing (fresh checkout or wiped state), the hub opens empty. No migration from older layouts - wipe `sim_state/` and start fresh.

### SD Card Slots

Both slots (own and guest) have identical UI:

- **Empty slot:** single `Choose card` button. Clicking it opens the **card picker modal**.
- **Occupied slot:** card name + `Eject` button. Eject clears the slot; the card returns to the registry and is available to any other slot.

**Card picker modal** lists every card in `cards.json` as a row showing the card name, an "in use elsewhere" hint when in use by another instance/slot, and a trash icon. It has a `+ New card` button at the top.

- **Pick a card:** tap a row. Cards in use by another instance/slot, or already in this instance's other slot, are greyed and not selectable.
- **+ New card:** prompts for a name (non-empty, must be unique), creates a fresh entry in `cards.json` with an empty `cards/<id>/` folder, and returns to the picker. Card init (PIN, `verify.bin`, etc.) runs the first time the card is mounted as `own`.
- **Trash icon:** disabled (greyed) while the card is in use anywhere. Otherwise prompts a confirm ("This wipes the card permanently") and on confirm removes the entry from `cards.json` and deletes `cards/<id>/`.

**Safety rail:** a card is considered "in use" iff some instance currently has it in its `own` or `guest` slot in `instances.json`. The card-picker greys out cards in use by another instance/slot, and the trash icon is disabled while a card is in use anywhere. Slot assignments - and therefore in-use state - persist across power cycles and Flask restarts, mirroring real hardware where an SD card stays physically inserted regardless of device power. Inserting the same card into both slots of the same instance is also disallowed.

**Exchange walkthrough in sim:**

1. On Alice's tab: tap `Contacts` → `+ Add contact` → enter a name → `Prepare exchange` → writes `X_own.bin` into Alice's mounted own card.
2. On Alice's tab: click `Eject` on the own slot. The card is now free.
3. On Bob's tab: in the guest slot, click `Choose card` → pick Alice's card from the list.
4. Bob runs the full streaming exchange, writing `OTP.bin` into Alice's card.
5. On Bob's tab: click `Eject` on the guest slot.
6. On Alice's tab: in the own slot, click `Choose card` → pick her card again → Alice finalizes, verifies checksum, splits, encrypts into `/secret/`, wipes `/exchange/`.

**Website Try-it coupling:** `matrixmole.com/otp-gadget` uses this simulator's
screen names, button labels, card moves, and sim-only `notify_screen` signals
as tutorial checkpoints. If the gadget UI flow changes, update the website
Try-it README and `try-it.ts` in the same change.

## Tests

Unit tests cover `core/` logic only - no hardware needed since core is plain Python. At minimum: OTP encrypt/decrypt correctness, key consumption and tracking, HMAC-SHA256 tag generation and verification, per-contact bookkeeping read/write, pad-split convention across both sides of an exchange, edge cases. Multi-contact-specific: manifest commit/delete/uniqueness (case-insensitive, trimmed; `in_flight.name` also blocks duplicates), `in_flight` lifecycle (set on add-start, committed-and-cleared on finalize success, cleared without commit on discard), `reconcile_in_flight()` recovery cases (stale marker no staging no pads → cleared; valid pads kind="add" → committed; valid pads kind="reexchange" → cleared), receive trial-decrypt picks the right contact across 3+ candidates and skips contacts with missing pads. UI and hardware flows are not tested.

## Waveshare Board Examples

Official MicroPython examples from the Waveshare wiki are mirrored at [`docs/waveshare-examples-repo/`](../docs/waveshare-examples-repo/). Use these as reference for the display driver, touch, and onboard peripherals.

## Hardware Bring-up Checklist

Things the simulator cannot prove. Each item must be verified once on the real board before trusting the firmware end-to-end. Failing any of these likely means reworking the approach, so they are checked early rather than after the full app is built.

| # | Check | How | Result | Notes / What to do if it fails |
|---|---|---|---|---|
| 1 | `cryptolib.aes` is available in the installed MicroPython build | REPL: `import cryptolib` | PASS | |
| 2 | CTR mode works | REPL: `cryptolib.aes(b'\x00'*32, 6, b'\x00'*16)` returns a cipher object | FAIL | CTR (mode 6) not available - `ValueError: mode`. ECB (mode 1) confirmed available. Using manual ECB-based CTR. ECB accepts multi-block buffers in one call (`aes.encrypt(bytes_4096)` processes 256 blocks in C), exploited by `CTRStream` for 4.6× throughput (24 → 111 KB/s). |
| 3 | ECB-based CTR seek behaves correctly for random-access pad slicing | Encrypt a known buffer, then decrypt a mid-buffer slice by computing `AES-ECB(DEK, IV + block_index)` XORed with ciphertext | PASS | Roundtrip and slice both verified - see bring-up log |
| 4 | PBKDF2 iteration throughput on RP2350 | Time a pure-Python PBKDF2 loop; pick an iteration count that yields ~1–2 s | done | Measured 603 iters/sec. Default = **1000 iterations** (~1.66 s). Stored per card in `/device/kdf_params.json`. |
| 5 | Guest SD does not interfere with LCD (both on SPI0) | Confirm screen stays fast after `mount_card("guest")` | FIXED | LCD and guest SD both used `SPI(0)`. SDCard.init_card() calls `spi.init(baudrate=100000)` which slowed the LCD to 100 kHz (full-screen fill ~24 s). Fixed by switching guest SD to `SoftSPI` on the same pins - SoftSPI does not touch the hardware SPI0 peripheral. |
| 6 | Onboard TF on SPI1 (GPIO26–31) mounts cleanly while SoftSPI guest SD is in use | Mount both cards back-to-back under the HAL | pending (7.3b) | Previously a concern due to SPI0 sharing; now SPI1 (own) and SoftSPI (guest) are fully independent. **Gotcha discovered during bring-up:** the guest SD module itself must be a **3.3V-only board** (no onboard regulator). Modules sold for Arduino (5V input → onboard AMS1117 → 3.3V → SD card) brown out when their VCC is wired to the Waveshare 3V3 rail - CMD0/CMD8 succeed but ACMD41 init fails with `OSError: timeout waiting for v2 card` after ~50 s of retries. See `docs/parts-and-products/index.md` → "SD Card Modules" for the only compatible part. |
| 7 | QR scanner (GM861XS) heartbeat + auto-config over UART1 on GPIO4/5 | `hal.qr_ping()` returns `True`; after a power-cycle, reading zone `0x0000` shows bits 1-0 = `01` and zone `0x0060` shows bits 6-5 = `01` and bit 0 = `1` | pending (7.3b) | Check UART wiring, baud, TX/RX polarity. If zone reads come back garbled, verify CRC-CCITT init value is `0` (not `0xFFFF`). |
| 8 | Display (ST7789) + touch (FT6336) both init without I2C contention | Boot a screen, read touch events | PASS | Display flashes correctly; FT6336U chip ID = 0x64; taps registered. See bring-up log. |
| 9 | Free SRAM after boot is enough for the streaming exchange, QR matrix, and keyboard state at the same time | `gc.mem_free()` after the app has started | PASS | 429 KB free at peak load (well above the 100 KB threshold). See bring-up log. |
| 10 | `uQR` generates a correct v22 matrix for a 500-byte payload and fits within a reasonable time budget | Drop `uQR.py` onto the board; generate a QR from a realistic 1028-char hex string; verify module count and scan it with a phone | PASS | uQR picks v22 (105 modules, 3.05 px/module) - one version larger than desktop `qrcode`'s v21. Two MicroPython compat patches applied to uQR (see bring-up log). Generation ~10 s. |
| 11 | Writing 5 MB of encrypted pad data to the onboard TF slot completes in acceptable time | Benchmark a full `pad_send.bin` write at card init | PASS | Write 334 KB/s, read 72 KB/s on Intenso 32 GB SDHC. Required patching `sdcard.py` (CRC stop-bit issue) - see bring-up log. |
| 12 | `hmac` module is available in the installed MicroPython build | REPL: `import hmac` | FAIL | Not available - `ImportError`. Writing a small wrapper around `hashlib.sha256` using the standard HMAC construction. |
| 13 | VBUS power-on suppression works: plugging in USB-C keeps the device off while charging | Power off the device, plug in a USB-C charger without pressing PWR; verify the screen stays dark and the device does not boot. Then press PWR while plugged in and verify normal boot. | pending | `RealHAL.__init__` reads `PWRON_STATUS` (reg 0x20) immediately after AXP init; if bit 2 (`vbus_pwron_stat`) is set and bit 0 (`btn_pwron_stat`) is clear, it calls `axp.power_off()` before any other init. The AXP2101 datasheet marks this VBUS power-on behavior as factory-customizable (EFUSE), so the actual default on the Waveshare board must be confirmed. If the bit is never set (VBUS power-on not wired on this board), the check is a harmless no-op. |

Results go in a short bring-up log (commit message or a file under `firmware/setup/`) so the next person building a device doesn't have to rediscover them.

## Crypto Pre-Spike (ESP32)

The ESP32 pre-spike was planned to de-risk the CTR design before the Waveshare board arrived, but was skipped - the board arrived first and the RP2350 bring-up supersedes it.

**RP2350 findings (MicroPython v1.28.0):**
- `import cryptolib` - available (PASS)
- CTR mode (mode 6) - not available (`ValueError: mode`) (FAIL)
- ECB mode (mode 1) - available (PASS)
- `import hmac` - not available (FAIL)

**Decision:** AES-CTR is implemented manually via AES-ECB keystream generation. HMAC is implemented as a small wrapper around `hashlib.sha256`. No different MicroPython build is needed.

See `firmware/setup/rp2350-bringup-log.md` for full details.

## Development Steps

All logic is developed and tested in the simulator first. Only after the simulator is working end-to-end is the firmware uploaded to hardware.

1. ~~ESP32 crypto pre-spike~~ - skipped; the Waveshare board arrived first. Crypto findings live in `setup/rp2350-bringup-log.md`.
2. Build simulator - implement `sim.py` HAL + Flask UI with hardware panel
3. Implement and test all `core/` logic against the simulator
4. Flash MicroPython `.uf2` onto the board (drag-and-drop via USB)
5. Deploy firmware with `scripts/flash.sh` and do a quick hardware smoke test - screen on, SD mounts, scanner responds to ping
6. Fix any wiring/hardware issues found in smoke test

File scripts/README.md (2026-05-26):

# scripts/

Utility scripts for development and deployment.

## For AI agents

These scripts are designed so an AI assistant can drive the connected hardware end-to-end without the user being in the loop, as long as the gadgets are plugged in via USB-C. The typical agent workflow:

1. `./scripts/inspect.sh list` - see which boards are connected and their labels.
2. `./scripts/flash.sh --label <name>` - flash a specific board non-interactively.
3. `./scripts/inspect.sh <label> enable-debug` and `watchdog-on` - turn on debug mode (file-based touch injection) and the watchdog.
4. `./scripts/inspect.sh <label> state` - read post-freeze state: last screen breadcrumb, reset cause, free RAM, SD mount status.
5. `./scripts/inspect.sh <label> click X Y` / `type "..."` / `macro <name>` - drive the UI remotely.

The agent only needs the user for physical actions (plugging USB, swapping SD cards, long-pressing PWR when the watchdog is off). Interactive prompts are only used when no `--label` is given.

## Index

- `flash.sh` - deploy firmware to a connected board (see below)
- `reset.sh` - soft-reset all connected boards (or one with `--label <name>`)
- `inspect.sh` / `inspect.py` - post-freeze debug: read breadcrumb/reboot history, inject touches, replay macros (see below)
- `run.sh` - start the simulator locally
- `sim_smoke.py` - end-to-end backend smoke test for the live demo path
  (health, site session creation, websocket, session status). Launch gate; run
  vs localhost and the deployed backend: `python3 scripts/sim_smoke.py [BASE_URL]`
- `qr_size_check.py` - one-off spike to determine max plaintext size for QR
- `qr_size_check_results.md` - output of the spike
- `cost_calculator.py` - prints a NOK-denominated cost breakdown (components, shipping, customs/VAT). Run with `python3 scripts/cost_calculator.py`. Not part of any release.
- `export_release.py` - export a public release folder from this private repo (see below)
- `release-manifest.public.yml` - whitelist for the public open-source release (firmware, parts list, order checklist, assembly, case docs, printable case `.3mf` files, etc.)
- `requirements.txt` - Python deps for the scripts venv
- `macros/` - named tap-sequence files for reproducing known bugs

## flash.sh

Deploys firmware source files to a connected RP2350 board via `mpremote`.

**Prerequisites:** `mpremote` must be installed (`pip install mpremote`).

**Usage:**

```bash
./scripts/flash.sh                       # interactive: pick a board from a list
./scripts/flash.sh --clean               # interactive, wipe firmware first
./scripts/flash.sh --label alice         # non-interactive: flash the board labeled "alice"
./scripts/flash.sh --label alice --clean # non-interactive, wipe firmware first
./scripts/flash.sh --all                 # non-interactive: flash every connected board
./scripts/flash.sh --all --clean         # non-interactive, all boards, wipe firmware first
./scripts/flash.sh --refresh-list        # force re-probing every connected board (ignore cache)
```

**Interactive mode** (no `--label` and no `--all`):

1. Lists all connected boards with their friendly label, firmware version hash, last-flashed timestamp, and an outdated indicator if the board's firmware doesn't match the local source.
2. Prompts you to pick one - type a board number, or `a` to flash all connected boards in sequence.
3. If the chosen board has no label yet, prompts for one and writes it to `/flash/device_label.txt`. (When flashing all, any unlabeled boards are prompted for in order.)

**Board listing cache:**

Probing a board with `mpremote` interrupts whatever firmware it's running (Ctrl-C → raw REPL → soft reset). To avoid disturbing idle boards every time you flash, listing data is cached at `~/.cache/otp-gadget-flash/board-cache.json`, keyed by serial port (`{port: {label, version, flashed_at}}`). On startup the script uses the cache for any connected port it already knows about; only unknown ports are probed live. The cache entry for a board is refreshed automatically after each successful flash of that board. Pass `--refresh-list` to discard the cache for all currently connected ports and re-probe every board (use this if you suspect the cache is stale, e.g. you flashed a board from another machine).

**Upload retry:**

If an `mpremote` call fails with a transient USB CDC error (e.g. "Device not configured", or "failed to access … it may be in use by another program"), the script retries the entire invocation up to 3 times with exponential backoff (2 s, then 4 s) so macOS has time to re-enumerate the device and release the previous file descriptor. If all 3 attempts fail, the script exits with the original error.

Between boards (when flashing several in one run), the script also waits 5 s after resetting the previous board before touching the next one - the post-reset USB churn can otherwise perturb the next board's CDC endpoint mid-upload.

**Non-interactive mode** (`--label <name>` or `--all`):

- `--label <name>`: finds the connected board whose `/flash/device_label.txt` matches `<name>` and flashes it directly. Errors out if no connected board has that label, or if the matching board is unlabeled.
- `--all`: flashes every connected board in sequence, in the order returned by `mpremote devs`. Errors out if any connected board is unlabeled (assign labels interactively first). `--label` and `--all` are mutually exclusive.
4. **Normal flash:** computes SHA-256 of each local source file. Reads the board's firmware manifest (`/flash/firmware_manifest.json`) to determine what has changed. Uploads only new or modified files, deletes files present on the board but removed from source. Skips the upload entirely if nothing changed.
5. **`--clean` flash:** wipes `/firmware/` entirely first, then uploads all files regardless of the manifest. Use this when you suspect the board is in a bad state or want a guaranteed clean slate. `/flash/` is always preserved (device label, `device_secret`, manifest).
6. Writes `/flash/firmware_manifest.json` **after** a successful upload (so a crashed upload never leaves a stale manifest). The manifest stores: per-file SHA-256 hash, an aggregate version hash (SHA-256 of the sorted per-file hashes), and a last-flashed UTC timestamp.
7. Resets the board so `main.py` starts running.

**Board listing example:**

```
Scanning for connected boards...
Local firmware: a1b2c3d

  1) alice   /dev/cu.usbmodem1101   a1b2c3d ✓  2026-05-11 14:32 UTC
  2) bob     /dev/cu.usbmodem1201   9f8e7d6 ⚠  2026-05-10 09:15 UTC  (outdated)
  3) carol   /dev/cu.usbmodem1301   (no manifest)
```

**What gets uploaded:**

| Path on laptop | Destination on board | Notes |
|---|---|---|
| `main.py` | `/main.py` | entry point |
| `firmware/__init__.py` | `/firmware/__init__.py` | package marker |
| `firmware/core/` | `/firmware/core/` | all business logic |
| `firmware/hal/__init__.py` | `/firmware/hal/__init__.py` | package marker |
| `firmware/hal/base.py` | `/firmware/hal/base.py` | HAL interface |
| `firmware/hal/real.py` | `/firmware/hal/real.py` | real hardware impl |
| `firmware/hal/drivers/` | `/firmware/hal/drivers/` | vendored MicroPython drivers |

The board mirrors the repo's `firmware/` package structure so all `from firmware.xxx import yyy` imports resolve the same way on the board as they do in the simulator.

**What is excluded:**

- `firmware/hal/sim.py` - simulator only, not needed on board
- `firmware/sim/` - Flask web app, not needed on board
- `firmware/tests/` - run on laptop, not on board
- `firmware/setup/` - one-time setup scripts, run manually if needed
- All `README.md` files

**Device labels:**

Each board stores its label in `/flash/device_label.txt` (e.g. `alice`, `bob`). The script preserves everything under `/flash/` across re-deploys (including `--clean`), so the label and `device_secret` survive. If the board's MicroPython is re-flashed via `.uf2` drag-and-drop, the label is lost and the script will prompt for it again on the next run.

**Firmware manifest (`/flash/firmware_manifest.json`):**

Written to the board after every successful flash. Contains:
- `version`: aggregate SHA-256 hash (hex) of all uploaded file hashes - the "firmware version"
- `flashed_at`: UTC timestamp of the last successful flash (ISO 8601)
- `files`: object mapping each file path to its SHA-256 content hash

The manifest is used on the next incremental flash to skip unchanged files. It is preserved across `--clean` flashes (written fresh after each run). If it is missing or corrupt, the script falls back to uploading all files.

**Multi-board workflow:**

Connect both boards and either run `./scripts/flash.sh --all` (non-interactive) or `./scripts/flash.sh` and pick `a` at the prompt. Boards are flashed one after another with a single invocation.

## reset.sh

Soft-resets all connected boards in one command. Useful after debugging sessions or when you want a clean boot without re-flashing.

**Usage:**

```bash
./scripts/reset.sh                  # reset all connected boards
./scripts/reset.sh --label alice    # reset only the board labeled "alice"
```

## inspect.sh

Diagnose post-freeze state and drive the UI remotely (debug mode only). Requires `mpremote` (same venv as `flash.sh`).

**Usage:**

```bash
./scripts/inspect.sh list                        # list connected boards (label, port, firmware version)
./scripts/inspect.sh <label> state               # one-shot snapshot of all state fields
./scripts/inspect.sh <label> click X Y           # inject one synthetic tap
./scripts/inspect.sh <label> type "hello"        # type via keyboard (flag --kb qwerty|digits|hex)
./scripts/inspect.sh <label> macro <name>        # replay scripts/macros/<name>.txt
./scripts/inspect.sh <label> enable-debug        # create /flash/debug_mode.txt + reboot
./scripts/inspect.sh <label> disable-debug       # delete /flash/debug_mode.txt + reboot
./scripts/inspect.sh <label> watchdog-on         # create /flash/watchdog.txt + reboot
./scripts/inspect.sh <label> watchdog-off        # delete /flash/watchdog.txt + reboot
./scripts/inspect.sh <label> reboot              # soft reset
./scripts/inspect.sh <label> tail-prints         # stream stdout from running script
```

**`state` output example:**

```
== alice (/dev/cu.usbmodem1101) ==
Last boot:        2026-05-11 14:32:17 UTC (cause: WDT)
Boot history:     3× WDT, 1× POWER_ON in last 4 boots
Last breadcrumb:  PrepareExchange.write_X_own@4194304/10485760
                  (2 s before last boot)
Recent trail:     (last 10 from /flash/breadcrumb_ring.txt)
                    PINEntry
                    Home
                    Contacts
                    PrepareExchange
                    PrepareExchange.write_X_own@524288/10485760
                    PrepareExchange.write_X_own@1048576/10485760
                    PrepareExchange.write_X_own@1572864/10485760
                    PrepareExchange.write_X_own@2097152/10485760
                    PrepareExchange.write_X_own@3145728/10485760
                    PrepareExchange.write_X_own@4194304/10485760
Live state:       responsive
Current screen:   Home (from /flash/last_state.txt, fresh)
I2C devices:      0x15 (touch), 0x34 (axp), 0x51 (rtc)  [all expected]
SD own:           MOUNTED
SD guest:         NO_CARD
Free RAM:         312 KB
Debug mode:       ON
Watchdog:         ENABLED (8 s)
```

**`list` output example:**

```
alice    /dev/cu.usbmodem1101    a1b2c3d  ✓  2026-05-11 14:32 UTC
bob      /dev/cu.usbmodem1201    9f8e7d6  ⚠  2026-05-10 09:15 UTC  (outdated)
[unlabeled]  /dev/cu.usbmodem1301    (no manifest)
```

**Touch injection** works only when debug mode is on (`/flash/debug_mode.txt` exists). The firmware polls `/flash/inject_queue.txt` on every `get_touch()` call; `inspect.sh click X Y` appends a line to that file. No mpremote exec interruption of the main loop. See `firmware/README.md` → `## Debug Tooling` for full details.

**Macros** live at `scripts/macros/<name>.txt` - one `click X Y`, `type "..."`, or `sleep N` per line. Comments start with `#`.

```
# Example: scripts/macros/freeze-prepare-exchange.txt
click 40 340          # Contacts
sleep 0.5
click 40 220          # + Add contact
```

## export_release.py

Exports a subset of this private repo to the public open-source repo.

- `--target public` writes a folder intended to be the working tree of the public open-source repo (`matrix-mole/otp-gadget` or equivalent). Includes everything a builder needs end-to-end: firmware, parts list, order checklist, assembly docs, case support docs, AND the printable case `.3mf` files.

Driven by `release-manifest.public.yml`. See [`docs/commercialization/open-source-release-strategy.md`](../docs/commercialization/open-source-release-strategy.md) for what belongs in the list and why.

**Prerequisites:**

```bash
python3 -m venv scripts/venv && source scripts/venv/bin/activate
pip install -r scripts/requirements.txt
```

**Usage:**

```bash
python scripts/export_release.py --target public                # writes ../otp-gadget/
python scripts/export_release.py --target public --dry-run      # list files, write nothing
python scripts/export_release.py --target public --force        # overwrite an existing output
```

**Pipeline:**

1. Read the manifest (`release-manifest.<target>.yml`).
2. Walk the repo from root, skipping `.git/` and `node_modules/`.
3. Keep files that match an `include` pattern and don't match any `exclude` pattern (gitignore-style globs via `pathspec`).
4. Run a secret scan on each included file: built-in patterns (GitHub/Google/AWS/Stripe keys, private-key headers, generic `secret = "..."` / `password = "..."` / `api_key = "..."` assignments) plus any `extra_secret_patterns` from the manifest. Binary files are skipped. Files listed in the manifest's `allowlist` may match without aborting.
5. On any unallowlisted match, the script exits with a list of offending files (no output written).
6. For each entry in the manifest's `render_html` list, render the source markdown to a self-contained HTML file (inline CSS, no external assets) and ship it next to the source. Not used by the public manifest today; kept as a generic capability.
7. On success: folder mode copies files preserving paths (existing `.git/` in the target is preserved by `--force`, the rest is wiped); zip mode writes a single archive.

The script is idempotent. A non-empty folder target or pre-existing zip refuses to overwrite without `--force`, so accidental re-runs can't silently destroy local edits.

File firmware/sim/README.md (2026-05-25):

# Simulator (`firmware/sim/`)

Flask web app that runs the real `core/` logic on a laptop, rendering the 320×480 screen in a browser. Used for development and as the live demo backend for the marketing site.

## Running locally

```bash
./dev.sh
```

`dev.sh` creates `.env` from `.env.example` on first run, loads it, then
launches the sim at `http://127.0.0.1:8080`. No env prefix needed, and no
database or Docker required - the sim is fully in-memory. The sim requires
`ALLOWED_ORIGINS`, `MAX_CONCURRENT_PAIRS`, `SESSION_IDLE_TIMEOUT_SECONDS`,
`SESSION_MAX_LIFETIME_SECONDS` (all asserted at startup; see `.env.example`).

## Index

- `app.py` - Flask + SocketIO server; admin hub (named persistent instances) + site session layer (see below)
- `templates/` - Jinja2 templates for the admin hub UI

## Admin hub

Named, persistent device instances used for manual development and testing. Accessible at `http://localhost:8080`. See `firmware/README.md → Simulator` for full docs.

## Deployment & origins

This Flask app is **backend-only**. The marketing/demo frontend lives in the
`matrix-mole` repo (Next.js) and is served by Vercel at
**`matrixmole.com/otp-gadget`**. This service is deployed separately on
Coolify/VPS at the backend-only subdomain
**`otp-gadget-sim.matrixmole.com`**:

- `/sim/*` → SocketIO WebSocket + HTTP
- `/api/*` → sim REST (site session lifecycle)

No static frontend is served here. (The old single-subdomain
`otp.matrixmole.com` setup is retired.)

**Socket.IO path:** the SocketIO engine endpoint is served at
**`/sim/socket.io`**, not the library default `/socket.io`. There is no proxy
path rewrite (see `plans/coolify-dns-runbook.md`), so the server path must
match the frontend's `NEXT_PUBLIC_OTP_SIM_URL` pathname (`.../sim`) →
`/sim/socket.io` in both local dev and production. The admin hub client uses
the same path.

Because the frontend is a different origin, `ALLOWED_ORIGINS` (asserted at
startup, comma-separated, no default) must list every frontend origin:

```
https://matrixmole.com,https://www.matrixmole.com,https://staging.matrixmole.com,http://localhost:3000
```

- `https://staging.matrixmole.com` - the permanent site-wide staging
  environment (Vercel domain bound to the long-lived `staging` branch). A
  stable alias is used instead of a `*.vercel.app` regex so flask-cors /
  Flask-SocketIO match an explicit origin.
- `http://localhost:3000` - Next dev server.

(The pre-migration values `https://otp.matrixmole.com` + `http://localhost:5173`
no longer apply.)

## Production runtime & build

Local dev uses the Werkzeug dev server (`./dev.sh`). **Production must not** -
it cannot hold the concurrent WebSocket load (up to `MAX_CONCURRENT_PAIRS` × 2
sockets). Production runs under **gunicorn with a single gevent-websocket
worker** (the long-standing Flask-SocketIO recipe; eventlet is deprecated
upstream). SocketIO requires sticky sessions, so the service runs one worker
and scales by container resources, not worker count:

```
gunicorn -k geventwebsocket.gunicorn.workers.GeventWebSocketWorker \
         -w 1 -b 0.0.0.0:$PORT firmware.sim.wsgi:app
```

- Binds `0.0.0.0` and honors Coolify's injected `$PORT` (the dev server's
  hardcoded `127.0.0.1:8080` is dev-only).
- The production path skips the dev-only interactive "kill port" prompt and the
  watchdog hot-reloader in `firmware/sim/__main__.py`.
- One-time startup work (stale-lock/session cleanup, `quick_demo` fixture bake)
  runs at app creation, before the first request.

**Build:** a `Dockerfile` at the **repo root** (build context = repo root, not
`firmware/sim/`) - the sim imports the `firmware` package and reads
`firmware/sim/fixtures` by relative path, so the whole `firmware/` tree must be
in the image. Installs `firmware/requirements.txt`. Coolify builds this
Dockerfile and auto-deploys on push to `main`.

**Health check:** `GET /healthz` returns `200 {"status":"ok"}` without touching
session state, for Coolify's container health probe. (`/` is the admin hub and
is not a health endpoint.) Coolify runs this probe with `curl` *inside* the
container, so the image installs `curl` (the `python:3.12-slim` base ships
without it; without `curl`/`wget` the probe always fails and Coolify rolls the
deploy back even though gunicorn is healthy).

**Rate limiter storage:** `flask-limiter` intentionally uses its default
in-memory storage for launch. Production runs one gunicorn worker/process, so
the counters are shared for all live requests in that process. They reset on
restart/redeploy and are not suitable for multiple workers/containers, but the
limited route is low-stakes:

- `POST /api/site/session` - `10 per hour` per client IP, protects simulator
  session creation from casual abuse and resource churn.

Do not add Postgres/Redis-backed limiter storage yet. Revisit if production
uses more than one worker/container, if redeploy-cleared counters become a real
abuse path, or if these endpoints become higher stakes.

**Production env vars** (set in Coolify's env UI, never committed - all asserted
at startup, no defaults):

| Var | Production value |
|---|---|
| `ALLOWED_ORIGINS` | the four frontend origins listed above |
| `MAX_CONCURRENT_PAIRS` | tuned against the VPS once Try-it works end-to-end |
| `SESSION_IDLE_TIMEOUT_SECONDS` | `300` |
| `SESSION_MAX_LIFETIME_SECONDS` | `600` |

`.env.example` mirrors these keys for local dev only with placeholder values.

**Removed endpoint:** `POST /api/kit-interest` was deleted when the website
interest form was removed. Do not keep dead form/table/DB plumbing in the sim.

**Smoke test:** `scripts/sim_smoke.py <base-url>` exercises the live demo path:
health check → create `quick_demo` site session (REST) → SocketIO WebSocket
connect → session status check. Run against `localhost` and against the
deployed backend as the launch gate.

**CI is intentionally deferred.** Coolify auto-deploys on push but its health
check only probes `/healthz` - it does not exercise Socket.IO/CORS/session, so a
deploy can be green yet functionally broken. Until backend changes become
frequent, the gate is manual: run `scripts/sim_smoke.py <deployed-url>` once
after any backend change. Revisit CI (whitelisted runner IP, since
`POST /api/site/session` is rate-limited to 10/hr per IP) if that cadence picks
up post-launch.

## Site session layer

A separate namespace alongside the admin hub, added for the
`matrixmole.com/otp-gadget` marketing/demo page. Two device instances (Alice +
Bob) per visitor session, destroyed when the session ends.

The website Try-it tutorials are tightly coupled to this simulator and the
firmware UI flow. If a gadget screen, button label, contact-exchange step,
message step, or sim-only `notify_screen` name changes, update the website's
`apps/website/app/otp-gadget/_lib/ui/README.md` and `try-it.ts` in
`matrix-mole` in the same change.

See `site/README.md → Simulator integration` for the full spec. Implementation tracked in `site/CHECKLIST.md` section 5a.

## Sim-only divergences from real hardware

These are intentional differences that only affect simulated sessions. Real-hardware behavior (`firmware/hal/real.py`) is unchanged.

### `preunlocked` HAL flag (SimHAL only)

**Purpose:** site demo sessions skip PIN entry entirely - gadgets boot directly to Home.

**How it works:**

`SimHAL` accepts `preunlocked=True`. When set:

1. A fixed dummy DEK (`\x00 * 32`) is injected into RAM at construction - `hal._dek` is set immediately.
2. `unlock_secrets()` and `lock_secrets()` become no-ops, keeping the dummy DEK in RAM for the lifetime of the session.
3. All secret I/O (`read_secret`, `write_secret`, `read_secret_slice`, `read_secret_stream`, `write_secret_stream`) skips AES entirely - files under `/secret/` are stored as plaintext on disk.
4. At construction, two stub files are auto-created if missing so `boot.py`'s checks pass without running DeviceSetup or CardInit:
   - `<state_dir>/mcu_flash/device_secret.bin` - dummy 32 bytes
   - `<own_card_path>/secret/verify.bin` - raw `VERIFY_MAGIC + _PREUNLOCKED_DUMMY` (no AES wrapper)

`boot.py` calls `_pin_entry(hal)` instead of `PINEntryScreen(hal).run()` directly. `_pin_entry` checks `getattr(hal, '_preunlocked', False)` and returns immediately when set, so PIN entry is a no-op for preunlocked sessions. `getattr` defaults to `False` for any HAL without the attribute (including `RealHAL`), so real hardware is unaffected.

**Security note:** this flag exists only in `SimHAL`, which runs only on a laptop. `RealHAL` has no `_preunlocked` attribute and is completely unmodified. Preunlocked sessions are never used outside the simulator.

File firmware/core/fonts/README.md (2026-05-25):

# Fonts

Pre-generated MicroPython font modules. Committed to the repo - do not regenerate unless the font or size changes.

## Index

- `font_14.py` - DejaVu Sans Mono, 14 px (messages, hex output, labels)
- `font_28.py` - DejaVu Sans Mono, 28 px (keyboard keys, headings)

## How to regenerate

Requires `freetype-py` (`pip3 install freetype-py`) and `font_to_py.py` from [peterhinch/micropython-font-to-py](https://github.com/peterhinch/micropython-font-to-py).

The output filename must start with a letter (tool validation), so run from this directory:

```sh
cd firmware/core/fonts

# Download font_to_py once
curl -sL https://raw.githubusercontent.com/peterhinch/micropython-font-to-py/master/font_to_py.py -o /tmp/font_to_py.py

# Copy font to a name without spaces (tool requirement)
cp "/path/to/DejaVuSansMono.ttf" /tmp/DejaVuSansMono.ttf

# Build charset: printable ASCII (32-126) + ↑↓ arrows used in ContactThread
python3 -c "print(''.join(chr(c) for c in range(32, 127)) + '↑↓', end='')" > /tmp/font_charset.txt

python3 /tmp/font_to_py.py -x -f /tmp/DejaVuSansMono.ttf 14 font_14.py -k /tmp/font_charset.txt
python3 /tmp/font_to_py.py -x -f /tmp/DejaVuSansMono.ttf 28 font_28.py -k /tmp/font_charset.txt
```

Flags: `-x` = horizontal bitmap mapping (row-by-row), `-f` = fixed-width pitch, `-k` = charset file.

The charset includes all printable ASCII plus `↑` and `↓` (used in the message thread prefix `S↑`/`R↓`). The generated files are sparse (only listed chars are stored), so adding these two glyphs adds negligible size.

Font source used: `DejaVu Sans Mono for Powerline.ttf` from `~/Library/Fonts/` (macOS). The standard `DejaVuSansMono.ttf` from the [DejaVu fonts project](https://dejavu-fonts.github.io/) produces identical glyphs for the ASCII range.

## Format

Each `.py` module exposes:

- `height()` - glyph height in pixels
- `max_width()` - glyph width in pixels (fixed, same for all chars)
- `hmap()` → `True` - rows are packed left-to-right, MSB first
- `reverse()` → `False` - 1 = lit pixel
- `get_ch(ch)` → `(bytearray, height, width)` - bitmap for one character

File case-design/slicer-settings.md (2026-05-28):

# PrusaSlicer Settings

Settings used on the original prints. Both shells, 0.4 mm nozzle.

| Setting | Value |
|---|---|
| Layer height | 0.2 mm |
| Infill density | 25% |
| Infill pattern | Gyroid |
| Perimeters (walls) | 4 |
| Top/bottom layers | 4 |
| Supports | Enabled, everywhere |
| Print speed | slicer default (untouched) |

Notes:

- **Supports everywhere.** Tested with and without; the supported version came out noticeably cleaner.
- **Infill pattern.** Gyroid was used, but the case is mostly thin shell — pattern barely matters here.
- **Re-exporting from Fusion 360.** Export as **3MF**, component only (hide electrical parts before export).

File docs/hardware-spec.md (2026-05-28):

# Hardware specification

Component-level detail for the OTP gadget hardware. For the buying guide (SKUs, prices, "do NOT use" notes), see [`order-checklist.md`](order-checklist.md). For chip-level identity at a security-review level, see [`parts-overview.md`](parts-overview.md).

## Hardware overview

- 3.5" capacitive touchscreen (phone-style touch, no stylus needed).
- QR code send/receive: sender's device displays ciphertext as a QR code; receiver's device scans it using a dedicated QR scanner module, eliminating manual hex entry entirely.
- 3D-printed casing with screwed-in components.
- One external USB-C port (charging + dev; see [USB ports](#usb-ports) below).
- Two MicroSD card slots: own card (internal TF slot on the display board) + guest card (external SPI breakout, accessible from outside the case for key exchange).
- On/off button (built into the display board).
- True random number generator via the RP2350's built-in hardware TRNG.

The device has two exposed MicroSD/TF card slots with fixed roles:

- **Onboard TF slot**: this device's permanent main card (`own card`).
- **External SPI MicroSD slot**: temporary guest/exchange card (`guest card`).

## USB ports

The device has one USB-C port, built into the RP2350-Touch-LCD-3.5 board.

**Single USB-C port — charging and dev:**

- Handles both LiPo battery charging (via the onboard AXP2101 power management chip) and firmware flashing during development.
- Mounted so it is accessible from the outside of the case.
- In normal use, the user plugs in any USB-C charger. No separate charging module or USB-C breakout board is needed.
- **Plugging in the cable does not power the device on.** The AXP2101 charges the battery in the background while the MCU stays off. To power on while charging, press the PWR button as normal.
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

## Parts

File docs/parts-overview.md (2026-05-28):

# Parts overview

What is physically inside the gadget, at the chip-identity level. Intended for independent security review of the build.

This is not a buying guide. Supplier links, SKUs, prices, and "do NOT use" notes live in [`docs/order-checklist.md`](order-checklist.md).

## What is in the gadget

### Waveshare RP2350-Touch-LCD-3.5 (pre-assembled module)

A single off-the-shelf module bought as one unit and not modified. Bundles the MCU, display, touch controller, PMIC, and an onboard MicroSD slot.

- **MCU**: Raspberry Pi RP2350B. Dual Cortex-M33, 520 KB SRAM. Hardware TRNG on silicon - the source of all OTP key bytes. No software PRNG is used to generate key material.
- **Display**: 3.5 inch IPS LCD, 320x480. Display controller is **ST7789** (SPI, passive driver chip, no firmware, no radio).
- **Touch**: capacitive panel with **FT6336U** controller (I2C, passive).
- **PMIC / charger**: **AXP2101**. Battery charging, voltage regulation, on/off button. Controlled by I2C; otherwise a passive power-path chip.
- **Onboard MicroSD slot**: standard TF socket wired to the MCU via SPI. No chip on the socket - just contacts and a pinout.
- **RTC chip**: **PCF85063**. On the module's internal I2C1 bus (no external wiring required). Used by the firmware for PIN-cooldown persistence: the cooldown deadline is stored as a wall-clock unix timestamp and checked against `hal.rtc_now()`, so power-cycling the device does not shortcut the wait. Runs off the same LiPo as the MCU.

### External components added by this design

- **QR scanner**: GM861XS UART module. TTL serial at 3.3V. Internally contains an image sensor and microcontroller running closed vendor firmware - it does image processing and outputs only the decoded text string over UART. It has no on-board storage, no display, and no radio. From the main MCU's point of view it is a one-way "type text" device.
- **Guest MicroSD breakout**: bare passive board with a card socket and a pinheader. No regulator, no level shifter, no IC of any kind. Pure passthrough at 3.3V.
- **Battery**: single-cell 3.7V lithium polymer, around 1800 mAh, with a 2-pin connector. Standard hobby chemistry.
- **USB-C connector**: built into the Waveshare module. Used for charging and, in development mode, for flashing firmware. Not used for normal operation.

## What is deliberately not in the gadget

This is the core trust claim. None of the following exist anywhere on the device:

- No wifi chip
- No Bluetooth chip
- No cellular modem (GSM, LTE, 5G)
- No LoRa or other long-range radio
- No GPS receiver
- No microphone
- No speaker
- No camera exposed to the main MCU (see the QR scanner note above for the trust boundary on its internal sensor)
- No external flash or EEPROM beyond the MicroSD cards the user inserts
- No second general-purpose MCU under the main MCU's control

If a device claims to be this gadget but contains any of the above, it is not this design.

## Notes for security review

- **Entropy**: OTP key bytes come from the RP2350's on-silicon TRNG. See `firmware/core/crypto/` and `firmware/hal/real.py` (`get_random_bytes`).
- **Egress**: in normal use, the only data path out of the device is the screen showing a QR code. The only data path in is the QR scanner reading a QR code.
- **Storage**: long-lived secret material on either MicroSD card lives under `/secret/` and is encrypted at rest (pads, contacts, settings, master key, verify token). KDF parameters under `/device/` (card salt, version marker) are plaintext - these are not secrets and have to be readable to derive the key. Material under `/exchange/` (raw OTP bytes during the key-exchange ceremony) is plaintext by design - the point of the exchange is to hand those bytes to the other person. Used pad bytes are overwritten with fresh random bytes after use (pad shredding). See `firmware/core/crypto/` and `firmware/hal/real.py` (`write_secret`, `overwrite_secret_slice`).
- **Trust boundary on the QR scanner**: the GM861XS runs closed vendor firmware. The trust assumption is that it does not exfiltrate (it has no radio and no way to). What it can do, in principle, is alter the decoded string before sending it over UART. This is the same risk as any external sensor with vendor firmware and is mitigated by the fact that all decoded messages are encrypted ciphertext that the scanner cannot meaningfully tamper with without breaking decryption on the recipient.
- **No real-time clock in use**: nothing in the firmware depends on wall-clock time. Anti-replay and pad-position tracking are byte-offset based, not time-based.

## Pointers

- Buying guide and supplier links: [`docs/order-checklist.md`](order-checklist.md).
- Wiring: `assembly/` (rendered diagram). Editable source files (`assembly/*.af`) are not shipped publicly.
- Case design: `case-design/README.md`, `case-design/slicer-settings.md`, preview images, and the printable `.3mf` files (`Case bottom.3mf`, `Case top.3mf`, `Case-slice-file.3mf`) - all public under CC BY-SA 4.0.
- Firmware: `firmware/`.

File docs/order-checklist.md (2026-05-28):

# Order checklist

Everything you need to buy to build one OTP gadget. You will want to build at least two (the device only does anything useful when paired with a second one), so order for two builds.

> **Skip the temptation to substitute parts before checking the "Do NOT use" notes below.** Two of the SD card modules sold on AliExpress look almost identical to the one we use but are incompatible. Picking the wrong one costs half a day of debugging.

## Waveshare - https://www.waveshare.com

- [ ] **RP2350-Touch-LCD-3.5** - $25 each - https://www.waveshare.com/rp2350-touch-lcd-3.5.htm
  - 3.5 inch IPS touchscreen, RP2350B MCU, AXP2101 PMIC, onboard MicroSD slot, USB-C. The brain and the screen of the gadget in a single pre-assembled module.

## RS Components - https://www.rs-online.com

- [ ] **RS PRO 3.7V 1800mAh LiPo battery** - ~$21 each - https://no.rs-online.com/web/p/speciality-size-rechargeable-batteries/1449405
  - 53.5 x 35 x 10.4 mm, bare wires. Other 3.7V LiPo cells in similar dimensions work too; this is just the one that fits the case nicely. The deep link above is to the Norway store — RS has equivalent stock in most countries; search the local RS site for the SKU or for "RS PRO 1800 mAh".

## AliExpress - https://www.aliexpress.com

- [ ] **GM861XS QR scanner** - $12 each - https://www.aliexpress.com/item/1005006716675651.html
  - UART (TTL 3.3V), tiny form factor (about 17 mm round, 5 mm deep, 1 g). This is the chosen primary scanner. Other GM-series scanners use the same UART protocol but are physically larger.

- [ ] **Generic MicroSD SPI 3.3V module** (the bare 6-pin variant, no regulator, no level shifter) - $0.50 each - https://www.aliexpress.com/item/1005010794549615.html
  - Used as the external "guest" card slot. **The 3.3V-only constraint is non-negotiable** - see the "Do NOT use" section below.

- [ ] **MX1.25 2-pin cable, single head, 10 cm** - $1.30 - https://www.aliexpress.com/item/1005007277110532.html
  - Connects the battery to the JST socket on the Waveshare board. Order one pack; one cable per gadget.

## Card storage - any retailer

- [ ] **2x MicroSD card, 32 GB, Class 10** - one for your own card, one for the guest slot of whoever you pair with.
  - We use the Intenso 32 GB Class 10 (Norwegian retailer batterionline.no: https://www.batterionline.no/intenso-32-gb-micro-sd-hukommelseskort-incl-adapter-class-10), but any reputable Class 10 card from a major brand works (SanDisk, Kingston, Samsung). Avoid no-name cards from random AliExpress listings - card reliability matters for OTP key material.

---

## Do NOT use

These look almost identical to the SD module above and will break the gadget. They are listed here so you can recognize and reject them.

- ❌ **MicroSD SPI module with level converter** (5V/3.3V, has an onboard AMS1117 regulator)
  - https://www.aliexpress.com/item/1005001309671718.html
  - Why: requires 4.5-5.5 V on VCC. The gadget's header only exposes 3.3 V on battery power. The card will fail ACMD41 init with `OSError: timeout waiting for v2 card` after about 50 seconds of retries.
  - How to recognize: 4-pin SOT-223 regulator on the board, optional 8-pin level-shifter IC, listing claims "5V/3.3V" or "4.5-5.5V".

- ❌ **Mini MicroSD SPI standard variant** (also has onboard regulator)
  - https://www.aliexpress.com/item/32346771288.html
  - Same problem as above.

**What to look for** when sourcing a different SD module than the one linked:

- Listing explicitly says "3.3V only" (not "5V/3.3V")
- Small board (~18 x 18 mm), exactly 6 pins (`CS, SCK, MOSI, MISO, VCC, GND`)
- No visible ICs at all on the board - just the card socket and the pin header
- No mention of "level converter", "AMS1117", or any regulator chip

---

## Tools you also need (not included in the pack)

These are normal hobby electronics tools. If you already build things at home you probably have all of them.

- 3D printer (or access to one). FDM, build volume at least 150 x 100 x 60 mm.
- Soldering iron with a fine tip, solder, flux.
- Small Phillips screwdriver.
- Helping hands or a small vise.
- USB-C data cable (not charge-only).
- Multimeter (optional, useful for debugging).

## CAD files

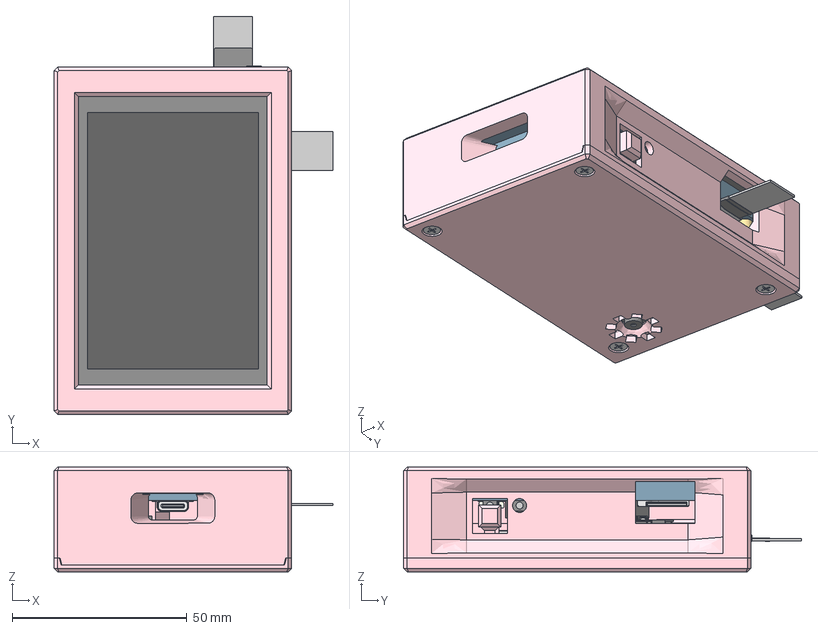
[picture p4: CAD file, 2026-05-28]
case-design/Case.step
79.8 x 113.9 x 30.0 mm
case_top
qr-scanner-GM861XS
RS PRO, 3.7 V, Lithium Polymer Rechargeable Battery, 1.8 Ah
case_bottom
screw x 6
Micro SD-Card x 2
473521001_microSD
DS1071-1x1 x 16
1x6 Male Pin Header Angle
2x1 Male Pin Header Angle x 8
tongue
shield
contact_001
contact_002
contact_003
contact_004
contact_court_001
contact_court_002
contact_court_003
contact_court_004
contact_005
contact_006
contact_007
contact_008
contact_court_005
contact_court_006
contact_court_007
contact_court_008
pin_001 x 9
pin_002
pin_003
pin_004
pin_005
pin_006
pin_007
pin_008
L-KLS1-TF-003_Connector
button x 3

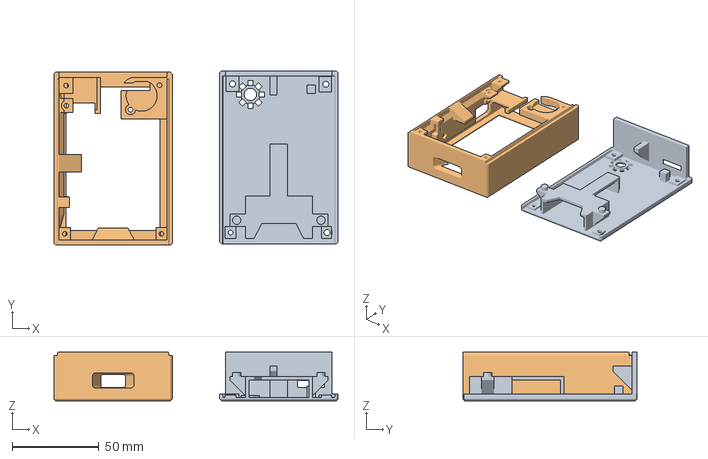
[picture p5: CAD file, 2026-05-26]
case-design/Case-slice-file.3mf
163.2 x 100.2 x 28.0 mm
Case bottom
Case top

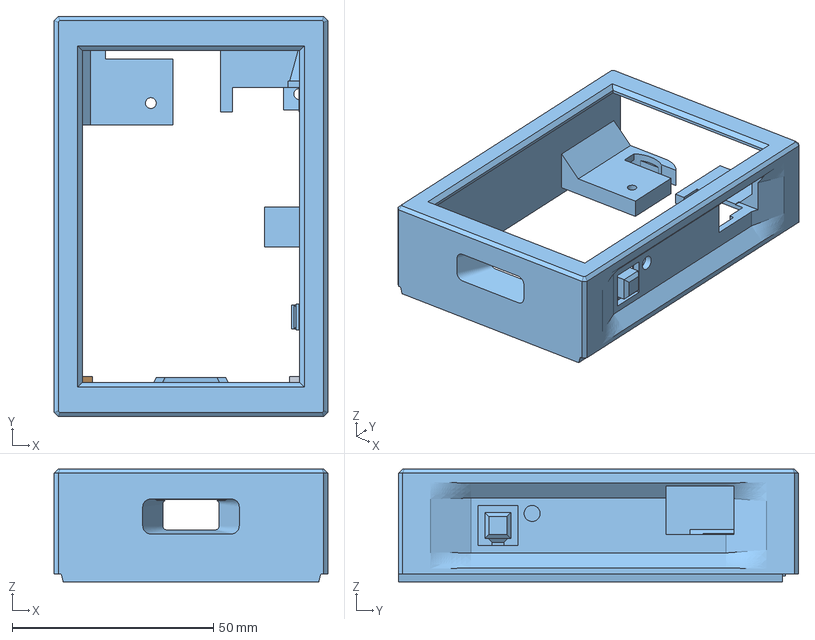
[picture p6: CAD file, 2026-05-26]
case-design/Case top.3mf
68.0 x 99.4 x 28.0 mm
sd screw platform

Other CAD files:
case-design/Case bottom.3mf
case-design/Case.f3z

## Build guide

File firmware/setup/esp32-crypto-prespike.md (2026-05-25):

# ESP32-C6 Crypto Pre-Spike

> **SKIPPED.** The Waveshare RP2350 board arrived before this pre-spike was run. The same questions were answered directly on the real target - see `rp2350-bringup-log.md`. The rest of this document is kept for reference only.

Goal: confirm that MicroPython's `cryptolib.aes` supports **AES-256-CTR** and that we can **seek to an arbitrary counter block** (needed for `hal.read_secret_slice`). This de-risks the `/secret/` encryption design before we start building the simulator.

The Waveshare RP2350 board hasn't arrived, so we use the ESP32-C6 DevKitC-1 as a stand-in. Same `cryptolib` module, different MCU port. A pass here is a strong signal, not final proof - items 1–3 of the bring-up checklist are re-run on the Waveshare board later.

## What you need

- ESP32-C6 DevKitC-1 (already have)
- USB-C cable (data, not just charging)
- Mac with Thonny installed (https://thonny.org)

## Step 1 - Download MicroPython firmware

1. Go to https://micropython.org/download/ESP32_GENERIC_C6/
2. Download the latest stable `.bin` (as of writing: `ESP32_GENERIC_C6-20260406-v1.28.0.bin`)
3. Save it to `~/Downloads/` (exact location doesn't matter, just remember it)

## Step 2 - Connect the board

The board has **two USB-C ports**. Use the one labeled **"USB"** (the native USB Serial/JTAG port built into the ESP32-C6 chip). **Not** the one labeled "UART" - that one needs a CP210x driver.

Plug the USB-C cable into the **USB** port and into your Mac.

Verify the Mac sees it:

```bash
ls /dev/cu.usb*
```

You should see something like `/dev/cu.usbmodem101` or similar. Note the full path.

## Step 3 - Flash MicroPython

Thonny can flash firmware directly - no command line needed.

1. Open Thonny
2. Tools → Options → Interpreter
3. Interpreter dropdown: **MicroPython (ESP32)**
4. Port: the `/dev/cu.usbmodem…` from step 2
5. Click **"Install or update MicroPython (esptool)"** at the bottom
6. In the dialog:
   - Target port: your port
   - MicroPython family: **ESP32-C6**
   - Variant: **Espressif • ESP32-C6 / 4MB flash**
   - Version: latest stable (matches what you downloaded)
7. Click **Install**. Takes ~30 s.
8. Close the dialogs. Thonny should auto-connect to the board and show `>>>` in the bottom shell.

If the shell doesn't appear: Run → Stop/Restart backend. Or unplug/replug the USB cable and hit the shell's red stop button.

## Step 4 - Run the crypto tests

Paste this whole block into the Thonny REPL (the `>>>` shell at the bottom) and hit Enter:

```python
import cryptolib, os

# ---- Test 1 & 2: cryptolib + CTR mode available ----
print("TEST 1: import cryptolib ... OK")
try:
    c = cryptolib.aes(b'\x00'*32, 6, b'\x00'*16)  # mode 6 = CTR
    print("TEST 2: AES-256-CTR constructor ... OK")
except Exception as e:
    print("TEST 2: AES-256-CTR constructor ... FAIL:", e)
    raise SystemExit

# ---- Test 3: encrypt/decrypt roundtrip ----
key = os.urandom(32)
iv  = os.urandom(16)
pt  = b'A' * 64  # 4 blocks of 16 bytes

enc = cryptolib.aes(key, 6, iv)
ct  = enc.encrypt(pt)

dec = cryptolib.aes(key, 6, iv)
rt  = dec.decrypt(ct)
print("TEST 3: roundtrip ...", "OK" if rt == pt else "FAIL")

# ---- Test 4: seek-to-counter (the critical one) ----
# Goal: decrypt only ct[32:48] (block index 2) without touching blocks 0,1,3.
# For CTR, the IV fed into the cipher acts as the starting counter block.
# So to decrypt from block N, construct IV' = (iv_as_int + N) as 16 big-endian bytes.

def add_counter(iv_bytes, n):
    x = int.from_bytes(iv_bytes, 'big') + n
    return (x & ((1 << 128) - 1)).to_bytes(16, 'big')

try:
    seek_cipher = cryptolib.aes(key, 6, add_counter(iv, 2))
    slice_pt = seek_cipher.decrypt(ct[32:48])
    print("TEST 4 (native CTR seek) ...", "OK" if slice_pt == pt[32:48] else "FAIL")
except Exception as e:
    print("TEST 4 (native CTR seek) ... FAIL:", e)

# ---- Test 5: ECB fallback for seek (plan B if test 4 fails) ----
# Build keystream manually: ECB-encrypt the counter block, XOR with ciphertext slice.
try:
    ecb = cryptolib.aes(key, 1, )  # mode 1 = ECB
except TypeError:
    ecb = cryptolib.aes(key, 1)    # some builds accept no IV for ECB

ks_block = ecb.encrypt(add_counter(iv, 2))
slice_pt_fb = bytes(a ^ b for a, b in zip(ct[32:48], ks_block))
print("TEST 5 (ECB fallback seek) ...", "OK" if slice_pt_fb == pt[32:48] else "FAIL")

# ---- Test 6: hmac module availability (bonus - used for message auth) ----
try:
    import hmac
    print("TEST 6: import hmac ... OK")
except ImportError:
    print("TEST 6: import hmac ... FAIL (will need hashlib-based wrapper)")

print("DONE")
```

## Step 5 - What the results mean

| Result | Meaning |
|---|---|
| Tests 1–3 OK | `cryptolib` + CTR work. Core encryption design is safe. |
| Test 4 OK | Native CTR seek works. `read_secret_slice` is simple - just pass an adjusted IV. |
| Test 4 FAIL, Test 5 OK | We use the ECB fallback path for `read_secret_slice`. Still fine, just slightly more code. |
| Tests 1, 2, or 3 FAIL | Big deal. The `/secret/` design has to change. Stop and tell me. |
| Test 6 FAIL | Minor. We'll write a ~10-line HMAC wrapper around `hashlib.sha256`. |

## Step 6 - Record the results

Copy the **full console output** into `firmware/setup/esp32-crypto-prespike-results.md` (a template exists - just fill in the fields). Commit it.

That file is the source of truth for which code path `real.py` will take when we implement `read_secret_slice` later.

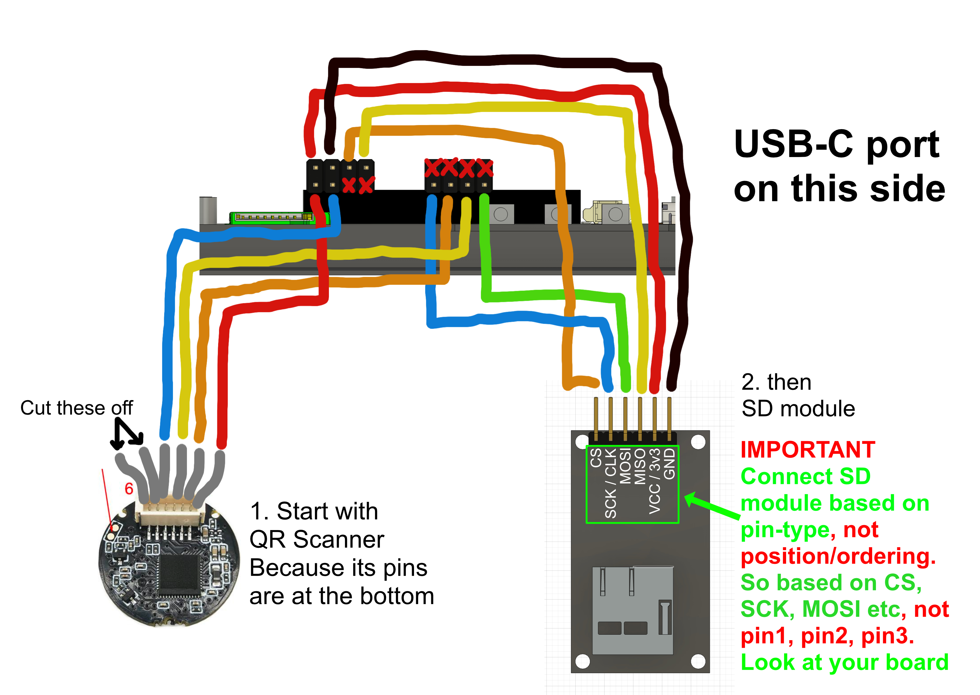
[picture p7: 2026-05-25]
assembly/how-to-connect-components.jpg

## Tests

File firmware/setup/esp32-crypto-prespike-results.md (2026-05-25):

# ESP32-C6 Crypto Pre-Spike - Results

Skipped. The Waveshare RP2350 board arrived before this was run. The RP2350 bring-up supersedes it - see `rp2350-bringup-log.md`.

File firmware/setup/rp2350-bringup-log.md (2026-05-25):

# RP2350 Hardware Bring-up Log

Board: Waveshare RP2350-Touch-LCD-3.5
MicroPython: v1.28.0 (2026-04-06) - `firmware/setup/RPI_PICO2-20260406-v1.28.0.uf2`
Date: 2026-04-25

## Checklist results

### 1 - `import cryptolib` - PASS

### 2 - CTR mode (mode 6) - FAIL

```
>>> cryptolib.aes(b'\x00'*32, 6, b'\x00'*16)
ValueError: mode
```

ECB mode (mode 1) is available:

```
>>> cryptolib.aes(b'\x00'*32, 1)
<aes>
```

**Decision:** implement AES-CTR manually using AES-ECB. For each 16-byte block N, keystream is `AES-ECB(DEK, IV + N)`, XORed with the ciphertext. This covers both sequential encryption and random-access pad slicing.

### 12 - `import hmac` - FAIL

```
>>> import hmac
ImportError: no module named 'hmac'
```

**Decision:** write a small wrapper around `hashlib.sha256` using the standard HMAC construction.

### 3 - ECB-based CTR seek - PASS

Verified that the keystream-via-ECB approach roundtrips correctly and that decrypting a mid-buffer slice with the right starting block index matches the plaintext slice. Confirms `read_secret_slice` can be implemented with manual ECB.

```
Full roundtrip: True
Slice match: True
```

### 4 - PBKDF2 throughput - done

Pure-Python PBKDF2-HMAC-SHA256 (using the manual HMAC wrapper) measured at:

```
1000 iters: 1658 ms
iters/sec: 603
```

Slower than the README's pre-measurement guess of 5,000–10,000 iters for 1–2 s. The HMAC wrapper does 2 SHA-256 calls per iteration, and SHA-256 in pure-Python on RP2350 is the bottleneck.

**Decision:** default iteration count = **1000** (≈1.66 s on this board). Stored per card in `/device/kdf_params.json` so it can be raised later without breaking existing cards.

### MicroPython firmware switch (mid-bring-up)

The initial flash used `RPI_PICO2-20260406-v1.28.0.uf2`, which is the build for
the standard Pi Pico 2 (RP2350**A**, only 30 GPIOs). On that build,
`Pin(31, Pin.OUT)` raises `ValueError: invalid pin` - and the Waveshare board
needs GPIO31 (onboard SD CS), GPIO32–33 (header SPI/UART), GPIO34/35
(touch I2C), etc.

Reflashed with `docs/waveshare-examples-repo/firmware/MicroPython/WAVESHARE_RP2350_Touch_LCD_3.5.uf2`,
the Waveshare-specific build for the RP2350**B** (full 48 GPIOs). All later
items are run on that build. The `RPI_PICO2` UF2 in `firmware/setup/` should
not be used for this board.

### 8 - Display (ST7789) + touch (FT6336U) - PASS

Test script: `firmware/setup/check_08_display_touch.py`. Requires `ST7789.py`
and `FT6336U.py` from the Waveshare examples on the board.

- Display flashes blue → red → black correctly (drivers/SPI on GPIO18-23 OK)
- Touch chip ID = `0x64` (correct, FT6336U on I2C1 GPIO34/35)
- 3 taps registered with sensible coordinates
- No I2C contention between touch and any other onboard peripheral

### 8b - Display orientation (MADCTL fix)

After running the full UI on the board, the display was horizontally mirrored
relative to the simulator (text reads right-to-left). The Waveshare example
ships MADCTL (`0x36`) = `0x08` (BGR, no axis flip), which on this panel
produces a mirrored portrait image.

**Fix:** MADCTL = `0x48` in `firmware/hal/drivers/st7789.py` - sets the MX bit
(column address direction reversed) on top of the BGR bit. Do not revert this
to match the upstream Waveshare example.

**Touch alignment check:** ran `firmware/setup/check_13_touch_alignment.py`
after the MADCTL fix. The original assumption in `real.py.get_touch` - that
the FT6336U reports landscape coordinates (`x` in 0..479, `y` in 0..319) and
must be rotated 90° - was wrong. The chip on this board reports **portrait
coordinates directly** (`x` in 0..319, `y` in 0..479). Five-target sweep
showed `raw_x ≈ portrait_x`, `raw_y ≈ portrait_y` to within finger-precision:

```
Target (30, 30)    raw (34, 45)
Target (290, 30)   raw (301, 38)
Target (160, 240)  raw (162, 246)
Target (30, 450)   raw (28, 441)
Target (290, 450)  raw (282, 450)
```

**Fix:** `get_touch` now returns `(raw_x, raw_y)` - no rotation. The
Waveshare example does `x = LCD_WIDTH - p['x']` because of how they orient
their demo, not because the chip needs rotation.

### 9 - Free SRAM after representative allocations - PASS

Test script: `firmware/setup/check_09_sram.py`. Allocates worst-case in-flight
buffers (101×101 QR matrix, keyboard state, 4 KB streaming chunk, 500-byte
plaintext) and reports `gc.mem_free()` at each step.

```
Free at start:         488,608 bytes  (477 KB)
After QR matrix alloc: 444,432 bytes  (used ~43 KB)
After keyboard alloc:  444,176 bytes  (used ~0 KB)
After 4 KB chunk buf:  440,048 bytes  (used ~4 KB)
After 500-byte msg:    439,472 bytes  (used ~0 KB)
Minimum free observed: 429 KB
```

Plenty of headroom (≥100 KB threshold; 429 KB observed).

### 10 - uQR generation for 500-byte payload - PASS

Test script: `firmware/setup/check_10_uqr.py`. Encodes a realistic 1028-char
hex frame (`offset 4B + length 2B + ciphertext 500B + tag 8B`).

```
Modes used: ['ALPHA_NUM']
QR version: 22
Modules (data): 105 × 105
px/module on 320 px screen: 3.05
Generation time: 10267 ms
```

**Two MicroPython compatibility issues found and patched in `uQR.py`:**

1. `QRData.write()` for `MODE_ALPHA_NUM` did `ALPHA_NUM.find(chars[0])`. In
   MicroPython, indexing into `bytes` yields `int`, and `bytes.find(int)`
   raises `TypeError`. Patched to use 1-byte slices: `chars[0:1]`, `chars[1:2]`.
2. `optimal_data_chunks` uses regex patterns that don't behave the same under
   MicroPython's `re` module - it falls through to `MODE_8BIT_BYTE` instead of
   `MODE_ALPHA_NUM` for hex strings. Workaround: callers must pass
   `optimize=0` to `add_data()`, which routes through `optimal_mode()` (a
   simple membership check) and correctly picks `MODE_ALPHA_NUM`.

**Discrepancy with desktop spike:** the desktop `qrcode` library picked v21
(101 modules) for the same payload; uQR picks v22 (105 modules). Both are
above the 3.0 px/module readability threshold on a 320 px screen. The 500-byte
plaintext cap holds. Generation time is ~10 s - acceptable for a one-shot
operation the user explicitly initiates.

### 11 - 5 MB pad write benchmark - PASS (after sdcard.py CRC fix)

Test script: `firmware/setup/check_11_pad_write_bench.py`. With the
Intenso 32 GB SDHC in the onboard slot:

```
Write done: 15288 ms  →  334 KB/s   (5 MB written in 4 KB chunks)
Read done:  70893 ms  →   72 KB/s   (5 MB read back, verified)
```

Write speed (334 KB/s) is plenty: 5 MB pad init takes ~15 s on first
exchange, and the per-message write footprint is tiny. Read speed (72 KB/s)
is slower but the firmware never does full-pad reads - per-message reads are
<1 KB via `read_secret_slice` with seek-to-block.

**Root-cause investigation - non-trivial.** The shipped `sdcard.py` driver
timed out at `init_card_v2` (`OSError: timeout waiting for v2 card`). All of
`CMD58`, `CMD55`, and `ACMD41` returned `-1` (no R1 byte at all). CMD0/CMD8
both worked. The card mounts cleanly on macOS.

**The bug:** every SD command frame's last byte ends with a stop bit (LSB =
1). `CMD0` and `CMD8` use `crc=0x95` and `crc=0x87` (LSB = 1, valid). All
other commands in the legacy driver pass `crc=0` (LSB = 0, **invalid stop
bit**). Most SD cards tolerate this; some - including this Intenso 32 GB -
silently refuse to respond.

**Fix:** patched `docs/waveshare-examples-repo/examples/MicroPython/02_SD/sdcard.py`
to pass `crc=0x01` (CRC7 = 0, stop bit set) instead of `crc=0` for every
command where CRC checking is don't-care (which is all of them in SPI mode
once CMD0 has been seen). Also bumped `_CMD_TIMEOUT` from 100 → 1000 as
belt-and-suspenders for slow cards (MicroPython issue #7129).

`real.py` will need to ship the patched `sdcard.py` - the unpatched Waveshare
copy will not work with the Intenso card.

## CTR mode fallout - master_key.py fix

`firmware/core/crypto/master_key.py` originally called `cryptolib.aes(key, 6, iv)`
(CTR mode) which is not available (see item 2 above). This would cause PIN unlock to
hard-fail the first time it ran on the board.

Fix (implemented in task 7.3a): the manual ECB-CTR construction is extracted into
`firmware/core/crypto/ctr.py` and `master_key.py` is updated to call `aes_ctr_xor`
from there. The sim continues to use pycryptodome's native CTR (separate code path,
same on-disk bytes). `real.py`'s `read_secret*` / `write_secret*` methods use the
same `ctr.py` helpers.

## Guest SD module compatibility (item 6 follow-up)

During end-to-end testing of two physical prototypes, both guest SD slots failed
to initialize with `OSError: timeout waiting for v2 card` after a ~50 s retry
loop. Symptoms:

- CMD0 succeeds (card responds with idle state) → SPI wiring + clocking are fine
- CMD8 succeeds (card identifies as v2) → bus is bidirectional at 100 kHz init
- ACMD41 loop never reaches "ready" → card never finishes internal init

Root cause was the **SD breakout module**, not the firmware, not the wiring, not
the cards. The two AliExpress modules ordered (items 1005001309671718 and
32346771288) both advertise "5V/3.3V" but in fact require **4.5–5.5 V on VCC**:
they have an onboard AMS1117-3.3 regulator with a ~1.0–1.3 V dropout. When VCC
is wired to the Waveshare header's 3V3 pin (the only power available on
battery), the regulator's output droops to ~2.0–2.3 V - enough for CMD0/CMD8's
tiny current draw, but **below the SD spec minimum** during ACMD41 init when
the card briefly draws ~50–100 mA.

The compatible module is **AliExpress item 1005010794549615** ("Generic MicroSD
SPI module 3.3V", 18.5×17.5 mm, no chips on the board - just the SD slot wired
straight to the 6-pin header). VCC goes to header pin 31 or 32 (3V3); no
regulator, no level shifter, works on USB and battery alike.

Documented in `docs/parts-and-products/index.md` ("SD Card Modules"), the root
`README.md` parts list, and `docs/datasheets/3.5inch-touchscreen/pin-diagram.md`
so the next person ordering parts doesn't re-discover this.

## Item 7 follow-up - GM861XS QR scanner wiring + bring-up (2026-05-13)

First physical bring-up of the GM861XS over UART1 (GPIO4 TX, GPIO5 RX). Three
findings worth recording so the next person doesn't re-debug them:

### a) Pin-diagram TX/RX labels were ambiguous

`docs/datasheets/3.5inch-touchscreen/pin-diagram.md` originally labelled pin
14/16 as "QR TX (UART1)" / "QR RX (UART1)" - readable two ways. The natural
reading "this is where the scanner's TX wire plugs in" is wrong; the correct
reading is "this is the board's TX line, which talks to the scanner's RX".
Fixed by changing the labels to `UART1 TX → QR RX` / `UART1 RX ← QR TX` with
matching arrows in the summary table and root `README.md` GPIO table. Test
script `firmware/setup/check_07_qr_scanner.py` (heartbeat) confirms wiring.

### b) Response-CRC offset bug in `hal/real.py::_qr_read_zone`

The scanner CRCs **request** frames over the full body (`Type+Len+Address+Data`),
but **response** frames are CRC'd over `Len+Address+Data` only, *excluding* the
leading Type byte at index 0. Verified empirically: response
`02 00 00 01 D6 98 8A` matches CRC over bytes 1..5, not 0..5.

`real.py` originally computed CRC over `rsp[:5]`, which would have thrown
`bad CRC` the first time `_qr_ensure_config` ran on real hardware. Fixed to
`rsp[1:5]`.

### c) Scanner ships with output routed to USB HID-KBW (zone 0x000D bit 0)

This was the headline gotcha. Symptom: heartbeat works, register reads/writes
work, trigger command is ACKed, the indicator LED flashes green on a valid QR
(decode succeeds internally) - but **no decoded data ever reaches the UART**.

Zone `0x000D` bits[1:0] control output routing:

| Value | Routing |
|---|---|
| `00`  | Serial port output |
| `01`  | USB PC Keyboard (HID-KBW)|
| `10`  | Keep / reserved |
| `11`  | USB virtual serial port  |

The factory default on the GM861XS unit ordered for this project was `01`
(HID-KBW) - i.e. decoded data is emitted as USB HID keystrokes, which is useless
on a UART-only wiring. Even though the GM861XS module has no USB pins broken
out, the firmware default still routes there and the UART data path stays
silent.

Fix: `_qr_ensure_config` now also clears bits[1:0] of zone `0x000D`, forcing
serial-port output. Saved to flash on first boot. Validated end-to-end with
`firmware/setup/check_12_qr_scan_loop.py` - a "hello world" QR on a phone
screen decodes as expected:

```
+856ms recv 20B: 0200000100333168656c6c6f20776f726c640d0a
>>> decoded: 'hello world'
```

(The leading `02000001003331` is the trigger-ACK; the trailing `0d0a` is the
CR+LF tail configured via zone `0x0060`.)

## Remaining items

- Items 5–6: pending end-to-end exercise of the guest SD slot in the live
  exchange flow (wiring + driver already proven; see "Guest SD module
  compatibility" above).

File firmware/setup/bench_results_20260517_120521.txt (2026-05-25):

Board: alice  (/dev/cu.usbmodem1201)
Date:  2026-05-17 10:05:21 UTC

  OTP Gadget – Exchange Speed Benchmark
  MicroPython 3.4.0; MicroPython v1.26.0-preview.370.gaa2362d4d.dirty on 2025-07-30

==============================================================
[1] TRNG  –  os.urandom throughput
==============================================================
  Source: os.urandom  (RP2350 hardware TRNG)
  Measuring (. = 1 MB): ..........
  10 MB in 86691 ms  →  118 KB/s
==============================================================
[2] XOR variants  –  4 KB chunks × 2560  (10 MB total)
==============================================================
  (Fixes 4 + 5 in the plan target the worst-case variants)

  bignum (. = 1 MB):      ..........
  bignum  (current):      10 MB in   13183 ms  →    776 KB/s
  bytearray (. = 1 MB):   ..........
  bytearray loop (Fix 4): 10 MB in  108299 ms  →     94 KB/s  (0.1× vs bignum)
  @native:                not available on this build
  @viper (Fix 5):         not available on this build
==============================================================
[3] AES-CTR  –  manual ECB-based CTR, 1 MB in 4 KB chunks
==============================================================
  (Relevant to the write side of all split phases)

  new cipher/block (. = 64 chunks): ....
  new cipher/block (current): 1 MB in 42548 ms  →  24 KB/s
  (65536 ECB calls for 1 MB; each creates a new aes object)
  cached cipher obj (. = 64 chunks): ....
  cached cipher obj:          1 MB in 41826 ms  →  24 KB/s  (1.0× vs new)
==============================================================
[4] SHA-256  –  streaming over 10 MB
==============================================================
  (Used during key generation and A-side verification)

  Measuring (. = 1 MB): ..........
  10 MB in 4694 ms  →  2181 KB/s
==============================================================
[5] SD clock speed matrix  (own card, onboard TF on SPI1)
==============================================================
  (Fix 3: raising the SDCard baudrate may give 2–5× improvement)
  Testing 1 MB write + read at each speed. Stops at first failure.

   5 MHz:  write  319 KB/s   read   73 KB/s   PASS
  10 MHz:  write  445 KB/s   read   78 KB/s   PASS
  15 MHz:  write  538 KB/s   read   81 KB/s   PASS
  20 MHz:  write  546 KB/s   read   81 KB/s   PASS
  25 MHz:  write  690 KB/s   read   83 KB/s   PASS

  → Best passing speed: 25 MHz
  → Gain vs 5 MHz:  write 2.2×  read 1.1×
==============================================================
[6] Composite phase  –  read 2 MB → AES-CTR encrypt → write 2 MB
==============================================================
  (Simulates one split-pad pass; using best SD speed from [5]: 25 MHz)

  2 MB (read + encrypt + write) in 119393 ms  →  17 KB/s effective

  ── Extrapolated total exchange time ──────────────────────
  Current A-side (3 read passes × OTP.bin):
    reads  20 MB at 83 KB/s  →  247 s
    writes 10 MB composite     →  602 s
    total  ≈ 849 s  (14.2 min)

  Fixed A-side (Fix 1+2: 1 combined read pass):
    reads  10 MB at 83 KB/s  →  123 s
    writes 10 MB composite     →  602 s
    total  ≈ 726 s  (12.1 min)

  A-side speedup from Fix 1+2 alone: 1.2×
==============================================================

  Benchmark complete.

  Restart firmware:   ./scripts/reset.sh --label <name>

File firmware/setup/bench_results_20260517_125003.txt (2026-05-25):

Board: alice  (/dev/cu.usbmodem1201)
Date:  2026-05-17 10:50:03 UTC

  OTP Gadget – Exchange Speed Benchmark
  MicroPython 3.4.0; MicroPython v1.26.0-preview.370.gaa2362d4d.dirty on 2025-07-30

==============================================================
[1] TRNG  –  os.urandom throughput
==============================================================
  Source: os.urandom  (RP2350 hardware TRNG)
  Measuring (. = 1 MB): ..........
  10 MB in 86753 ms  →  118 KB/s
==============================================================
[2] XOR variants  –  4 KB chunks × 2560  (10 MB total)
==============================================================
  (Fixes 4 + 5 in the plan target the worst-case variants)

  bignum (. = 1 MB):      ..........
  bignum  (current):      10 MB in   13488 ms  →    759 KB/s
  bytearray (. = 1 MB):   ..........
  bytearray loop (Fix 4): 10 MB in  110058 ms  →     93 KB/s  (0.1× vs bignum)
  @native:                not available on this build
  @viper (Fix 5):         not available on this build
==============================================================
[3] AES-CTR  –  manual ECB-based CTR, 1 MB in 4 KB chunks
==============================================================
  (Relevant to the write side of all split phases)
  (3c = new bulk-ECB variant not in the original benchmark)

  new cipher/block (. = 64 chunks): ....
  new cipher/block (current): 1 MB in 42562 ms  →  24 KB/s
  (65536 ECB calls for 1 MB; each creates a new aes object)
  cached cipher obj (. = 64 chunks): ....
  cached cipher obj:          1 MB in 42363 ms  →  24 KB/s  (1.0× vs new)
  bulk ECB (. = 64 chunks):  ....
  bulk ECB (Fix 6):           1 MB in 9185 ms  →  111 KB/s  (4.6× vs current)
==============================================================
[4] SHA-256  –  streaming over 10 MB
==============================================================
  (Used during key generation and A-side verification)

  Measuring (. = 1 MB): ..........
  10 MB in 4694 ms  →  2181 KB/s
==============================================================
[5] SD clock speed matrix  (own card, onboard TF on SPI1)
==============================================================
  (Fix 3: raising the SDCard baudrate may give 2–5× improvement)
  Testing 1 MB write + read at each speed. Stops at first failure.

   5 MHz:  write  320 KB/s   read   73 KB/s   PASS
  10 MHz:  write  439 KB/s   read   78 KB/s   PASS
  15 MHz:  write  509 KB/s   read   81 KB/s   PASS
  20 MHz:  write  460 KB/s   read   81 KB/s   PASS
  25 MHz:  write  538 KB/s   read   83 KB/s   PASS

  → Best passing speed: 25 MHz
  → Gain vs 5 MHz:  write 1.7×  read 1.1×
==============================================================
[6] Composite phase  –  read 2 MB → AES-CTR encrypt → write 2 MB
==============================================================
  (Simulates one split-pad pass; using best SD speed from [5]: 25 MHz)

  2 MB (read + encrypt + write) in 119931 ms  →  17 KB/s effective

  ── Extrapolated total exchange time ──────────────────────
  Current A-side (3 read passes × OTP.bin):
    reads  20 MB at 83 KB/s  →  247 s
    writes 10 MB composite     →  602 s
    total  ≈ 849 s  (14.2 min)

  Fixed A-side (Fix 1+2: 1 combined read pass):
    reads  10 MB at 83 KB/s  →  123 s
    writes 10 MB composite     →  602 s
    total  ≈ 726 s  (12.1 min)

  A-side speedup from Fix 1+2 alone: 1.2×
==============================================================

  Benchmark complete.

  Restart firmware:   ./scripts/reset.sh --label <name>

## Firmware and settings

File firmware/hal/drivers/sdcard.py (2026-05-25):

"""
MicroPython driver for SD cards using SPI bus.

Requires an SPI bus and a CS pin.  Provides readblocks and writeblocks
methods so the device can be mounted as a filesystem.

Example usage on pyboard:

    import pyb, sdcard, os
    sd = sdcard.SDCard(pyb.SPI(1), pyb.Pin.board.X5)
    pyb.mount(sd, '/sd2')
    os.listdir('/')

Example usage on ESP8266:

    import machine, sdcard, os
    sd = sdcard.SDCard(machine.SPI(1), machine.Pin(15))
    os.mount(sd, '/sd')
    os.listdir('/')

"""

from micropython import const
import time


_CMD_TIMEOUT = const(1000)  # bumped from 100 - some 32GB cards (e.g. Intenso) need >100 polls. See MicroPython issue #7129.
_WRITE_BUSY_TIMEOUT_MS = const(500)  # SD spec allows up to ~250 ms programming for SDHC; 500 ms gives headroom while still bounding a yanked card.

_R1_IDLE_STATE = const(1 << 0)
# R1_ERASE_RESET = const(1 << 1)
_R1_ILLEGAL_COMMAND = const(1 << 2)
# R1_COM_CRC_ERROR = const(1 << 3)
# R1_ERASE_SEQUENCE_ERROR = const(1 << 4)
# R1_ADDRESS_ERROR = const(1 << 5)
# R1_PARAMETER_ERROR = const(1 << 6)
_TOKEN_CMD25 = const(0xFC)
_TOKEN_STOP_TRAN = const(0xFD)
_TOKEN_DATA = const(0xFE)


class SDCard:
    def __init__(self, spi, cs, baudrate=1320000):
        self.spi = spi
        self.cs = cs

        self.cmdbuf = bytearray(6)
        self.dummybuf = bytearray(512)
        self.tokenbuf = bytearray(1)
        for i in range(512):
            self.dummybuf[i] = 0xFF
        self.dummybuf_memoryview = memoryview(self.dummybuf)

        # initialise the card
        self.init_card(baudrate)

    def init_spi(self, baudrate):
        try:
            master = self.spi.MASTER
        except AttributeError:
            # on ESP8266
            self.spi.init(baudrate=baudrate, phase=0, polarity=0)
        else:
            # on pyboard
            self.spi.init(master, baudrate=baudrate, phase=0, polarity=0)

    def init_card(self, baudrate):

        # init CS pin
        self.cs.init(self.cs.OUT, value=1)

        # init SPI bus; use low data rate for initialisation
        self.init_spi(100000)

        # clock card at least 100 cycles with cs high
        for i in range(16):
            self.spi.write(b"\xff")

        # CMD0: init card; should return _R1_IDLE_STATE (allow 5 attempts)
        for _ in range(5):
            if self.cmd(0, 0, 0x95) == _R1_IDLE_STATE:
                break
        else:
            raise OSError("no SD card")

        # CMD8: determine card version
        r = self.cmd(8, 0x01AA, 0x87, 4)
        if r == _R1_IDLE_STATE:
            self.init_card_v2()
        elif r == (_R1_IDLE_STATE | _R1_ILLEGAL_COMMAND):
            self.init_card_v1()
        else:
            raise OSError("couldn't determine SD card version")

        # get the number of sectors
        # CMD9: response R2 (R1 byte + 16-byte block read)
        if self.cmd(9, 0, 0x01, 0, False) != 0:
            raise OSError("no response from SD card")
        csd = bytearray(16)
        self.readinto(csd)
        if csd[0] & 0xC0 == 0x40:  # CSD version 2.0
            self.sectors = ((csd[8] << 8 | csd[9]) + 1) * 1024
        elif csd[0] & 0xC0 == 0x00:  # CSD version 1.0 (old, <=2GB)
            c_size = csd[6] & 0b11 | csd[7] << 2 | (csd[8] & 0b11000000) << 4
            c_size_mult = ((csd[9] & 0b11) << 1) | csd[10] >> 7
            self.sectors = (c_size + 1) * (2 ** (c_size_mult + 2))
        else:
            raise OSError("SD card CSD format not supported")
        # print('sectors', self.sectors)

        # CMD16: set block length to 512 bytes
        if self.cmd(16, 512, 0x01) != 0:
            raise OSError("can't set 512 block size")

        # set to high data rate now that it's initialised
        self.init_spi(baudrate)

    def init_card_v1(self):
        for i in range(_CMD_TIMEOUT):
            self.cmd(55, 0, 0x01)
            if self.cmd(41, 0, 0x01) == 0:
                self.cdv = 512
                # print("[SDCard] v1 card")
                return
        raise OSError("timeout waiting for v1 card")

    def init_card_v2(self):
        # NOTE: every command frame's CRC byte must end with bit 0 = 1 (the
        # stop bit). Some cards (e.g. Intenso 32GB SDHC) refuse to respond if
        # crc=0x00 is sent here. Use 0x01 (CRC7=0, stop bit set) when the
        # actual CRC is don't-care (SPI mode, CRC checking off by default).
        for i in range(_CMD_TIMEOUT):
            time.sleep_ms(50)
            self.cmd(58, 0, 0x01, 4)
            self.cmd(55, 0, 0x01)
            if self.cmd(41, 0x40000000, 0x01) == 0:
                self.cmd(58, 0, 0x01, 4)
                self.cdv = 1
                return
        raise OSError("timeout waiting for v2 card")

    def cmd(self, cmd, arg, crc, final=0, release=True, skip1=False):
        self.cs(0)

        # create and send the command
        buf = self.cmdbuf
        buf[0] = 0x40 | cmd
        buf[1] = arg >> 24
        buf[2] = arg >> 16
        buf[3] = arg >> 8
        buf[4] = arg
        buf[5] = crc
        self.spi.write(buf)

        if skip1:
            self.spi.readinto(self.tokenbuf, 0xFF)

        # wait for the response (response[7] == 0)
        for i in range(_CMD_TIMEOUT):
            self.spi.readinto(self.tokenbuf, 0xFF)
            response = self.tokenbuf[0]
            if not (response & 0x80):
                # this could be a big-endian integer that we are getting here
                for j in range(final):
                    self.spi.write(b"\xff")
                if release:
                    self.cs(1)
                    self.spi.write(b"\xff")
                return response

        # timeout
        self.cs(1)
        self.spi.write(b"\xff")
        return -1

    def readinto(self, buf):
        self.cs(0)

        # read until start byte (0xff)
        for i in range(_CMD_TIMEOUT):
            self.spi.readinto(self.tokenbuf, 0xFF)
            if self.tokenbuf[0] == _TOKEN_DATA:
                break
            time.sleep_ms(1)
        else:
            self.cs(1)
            raise OSError("timeout waiting for response")

        # read data
        mv = self.dummybuf_memoryview
        if len(buf) != len(mv):
            mv = mv[: len(buf)]
        self.spi.write_readinto(mv, buf)

        # read checksum
        self.spi.write(b"\xff")
        self.spi.write(b"\xff")

        self.cs(1)
        self.spi.write(b"\xff")

    def write(self, token, buf):
        self.cs(0)

        # send: start of block, data, checksum
        self.spi.read(1, token)
        self.spi.write(buf)
        self.spi.write(b"\xff")
        self.spi.write(b"\xff")

        # check the response
        if (self.spi.read(1, 0xFF)[0] & 0x1F) != 0x05:
            self.cs(1)
            self.spi.write(b"\xff")
            return
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

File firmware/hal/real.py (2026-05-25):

import os
import time

from machine import I2C, Pin, SPI, SoftSPI, UART, WDT

from firmware.hal.base import HALBase
from firmware.hal.drivers.axp2101 import AXP2101
from firmware.hal.drivers.ft6336u import touch_ft6336u
from firmware.hal.drivers.pcf85063 import PCF85063
from firmware.hal.drivers.st7789 import lcd_st7789
from firmware.hal.drivers import sdcard
from firmware.core.crypto.ctr import CTRStream, aes_ctr_xor

# RP2350 does not have os.urandom in all builds - detect once at import time.
try:
    os.urandom(1)
    _urandom = os.urandom
except (AttributeError, OSError):
    import random as _random

    def _urandom(n: int) -> bytes:
        buf = bytearray(n)
        i = 0
        while i + 4 <= n:
            v = _random.getrandbits(32)
            buf[i] = v & 0xFF
            buf[i + 1] = (v >> 8) & 0xFF
            buf[i + 2] = (v >> 16) & 0xFF
            buf[i + 3] = v >> 24
            i += 4
        while i < n:
            buf[i] = _random.getrandbits(8)
            i += 1
        return bytes(buf)


CHUNK = 4096

_FIRST_BOOT_UNIX = 1735689600  # 2026-01-01 00:00:00 UTC - RTC baseline


def _makedirs(path: str) -> None:
    """Create parent directories for path on FAT32 (ignores EEXIST)."""
    parts = path.split("/")
    cur = ""
    for p in parts[:-1]:
        if not p:
            continue
        cur = cur + "/" + p if cur else p
        try:
            os.mkdir(cur)
        except OSError:
            pass


class WriteHandle:
    def __init__(self, final_path: str) -> None:
        self._final = final_path
        self._tmp = final_path + ".tmp"
        _makedirs(self._tmp)
        self._f = open(self._tmp, "wb")

    def write(self, data: bytes) -> None:
        self._f.write(data)

    def seek(self, offset: int) -> None:
        self._f.seek(offset)

    def close(self) -> None:
        self._f.close()
        os.rename(self._tmp, self._final)

    def __enter__(self):
        return self

    def __exit__(self, exc_type, exc_val, exc_tb):
        try:
            self._f.close()
        except OSError:
            pass
        if exc_type is None:
            os.rename(self._tmp, self._final)
        else:
            try:
                os.remove(self._tmp)
            except OSError:
                pass
        return False


class EncryptedWriteHandle:
    def __init__(self, final_path: str, key: bytes) -> None:
        self._final = final_path
        self._tmp = final_path + ".tmp"
        _makedirs(self._tmp)
        iv = _urandom(16)
        self._stream = CTRStream(key, iv)
        self._f = open(self._tmp, "wb")
        self._f.write(iv)

    def write(self, data: bytes) -> None:
        self._f.write(self._stream.update(data))

    def close(self) -> None:
        self._f.close()
        os.rename(self._tmp, self._final)

    def __enter__(self):
        return self

    def __exit__(self, exc_type, exc_val, exc_tb):
        try:
            self._f.close()
        except OSError:
            pass
        if exc_type is None:
            os.rename(self._tmp, self._final)
        else:
            try:
                os.remove(self._tmp)
            except OSError:
                pass
        return False


class RealHAL(HALBase):

    _QR_HEARTBEAT_TX = b"\x7E\x00\x0A\x01\x00\x00\x00\x30\x1A"
    _QR_HEARTBEAT_RX = b"\x03\x00\x00\x01\x00\x33\x31"
    _QR_TRIGGER = b"\x7E\x00\x08\x01\x00\x02\x01\xAB\xCD"
    _QR_TRIGGER_ACK = b"\x02\x00\x00\x01\x00\x33\x31"
    _QR_SAVE_FLASH = b"\x7E\x00\x09\x01\x00\x00\x00\xDE\xC8"
    _QR_WRITE_ACK = b"\x02\x00\x00\x01\x00\x33\x31"

    def __init__(self) -> None:
        # Shared I2C1 bus for touch, battery, and RTC (all on GPIO34/35).
        # AXP2101 is initialized first so we can check the power-on source
        # before spending time on the display or other peripherals.
        self._i2c = I2C(1, scl=Pin(35), sda=Pin(34), freq=400_000)

        self._axp = AXP2101(self._i2c)
        self._axp.enable_pkey_irq()
        self._axp.pkey_short_pressed()  # drain any stale pre-boot press

        # Suppress VBUS-triggered auto-boot: if plugging in a USB-C cable
        # (not a button press) caused this power-on, power off immediately.
        # The AXP2101 continues charging the battery; only the MCU shuts down.
        # Users who want to use the device while charging press the button.
        # See firmware/README.md bring-up checklist item 13 for verification.
        if self._axp.pwron_was_vbus():
            self._axp.power_off()
            # Never reached; power_off() cuts MCU power via AXP2101.

        # Watchdog: enabled when /flash/watchdog.txt exists (toggle via inspect.sh watchdog-on/off).
        if self.flash_exists("watchdog.txt"):
            self._wdt = WDT(timeout=8000)
        else:
            self._wdt = None

        # Debug mode: file-based touch injection when /flash/debug_mode.txt exists.
        self._debug_mode = self.flash_exists("debug_mode.txt")

        self._lcd = lcd_st7789()
        self._touch = touch_ft6336u(bus=self._i2c)
        self._rtc = PCF85063(self._i2c)

        # Seed RTC on first boot (unix seconds == 0 means chip was reset)
        if self._rtc.read_unix() < _FIRST_BOOT_UNIX:
            self._rtc.set_time(2026, 1, 1, 0, 0, 0)

        # Own SD: SPI1 on GPIO26/27/28, CS on GPIO31
        self._own_spi = SPI(1, baudrate=10_000_000, polarity=0, phase=0,
                            bits=8, firstbit=SPI.MSB,
                            sck=Pin(26), mosi=Pin(27), miso=Pin(28))
        self._own_cs = Pin(31, Pin.OUT, value=1)
        self._own_mounted = False

        # Guest SD: SoftSPI on GPIO3 (MOSI) / GPIO32 (MISO) / GPIO6 (SCK), CS on GPIO33.
        # Must NOT use hardware SPI(0) here - the LCD also uses SPI0 (GPIO18/19).
        # SDCard.init_card() calls spi.init(baudrate=100000) which would slow the LCD
        # to 100 kHz (a full-screen fill takes ~24 s instead of ~16 ms).
        self._guest_spi = SoftSPI(baudrate=5_000_000, polarity=0, phase=0,
                                  bits=8, firstbit=SoftSPI.MSB,
                                  sck=Pin(6), mosi=Pin(3), miso=Pin(32))
        self._guest_cs = Pin(33, Pin.OUT, value=1)
        self._guest_mounted = False

        # QR scanner: UART1 on GPIO4 (TX) / GPIO5 (RX). Factory-default 9600 8N1.
        # Read mode + tail are reconfigured at runtime by _qr_ensure_config.
        self._qr_uart = UART(1, baudrate=9600, tx=Pin(4), rx=Pin(5),
                             bits=8, parity=None, stop=1, timeout=200)
        self._qr_configured = False

        # qr_poll state
        self._qr_poll_active = False
        self._qr_poll_buf = b""
        self._qr_poll_last = 0

        # In-RAM DEK
        self._dek: bytearray | None = None

    # -- Display ---------------------------------------------------------------

    def fill_rect(self, x: int, y: int, w: int, h: int, color: int) -> None:
        self._lcd.fill_rect(x, y, w, h, color)
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

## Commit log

2026-05-25 Initial public release
    Exported from the private working repo via scripts/export_release.py
    --target public. Open-source firmware (GPLv3) + docs (CC BY-SA 4.0).
    Printable case .3mf files are a separate paid Builder Pack.
    Builder-facing docs: https://matrixmole.com/otp-gadget/docs
2026-05-26 feat: open-source the printable case CAD; switch to fully open project
    The project is now fully open source. The three printable case .3mf
    files (Case bottom, Case top, Case-slice-file) are now in this repo
    under CC BY-SA 4.0 -- no more Builder Pack paywall.
    Doc updates across README, case-design/README, docs/parts-overview,
    and scripts/README to reflect the switch and point at GitHub
    Sponsors for donations.
    [Case bottom.3mf, Case top.3mf, Case-slice-file.3mf]
2026-05-26 docs: add case preview images
2026-05-26 chore: add .github/FUNDING.yml (GitHub Sponsors button)
2026-05-27 docs: extract protocol / security / hardware specs into dedicated files
    The long-form spec content that used to live only in the private README is
    now in five new public docs:
    - docs/protocol.md key exchange, wire format, message authentication
    - docs/security.md SD card layout, AES-256-CTR, KEK/DEK, TRNG, weaknesses
    - docs/hardware-spec.md hardware overview, USB, controls, GPIO allocation
    - docs/user-flows.md Home/Contacts/Settings/PIN/Send/Receive/history
    - docs/error-handling.md error classes, security invariant, recovery screen
    README gains a Documentation table indexing these.
2026-05-28 docs: document one-time MicroPython .uf2 install + drop CAD-only checklist
    firmware/README.md: add "First-time board setup" section covering the
    one-time MicroPython .uf2 install (Waveshare URL, BOOTSEL drag steps)
    with a prominent ordering warning — BOOTSEL is not exposed through
    the assembled case, so flashing has to happen before assembly.
    case-design/: drop BEFORE-PRINT-CHECKLIST.md (it was three Fusion-
    internal CAD-designer reminders, not print prep). Clean up references
    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
2026-05-28 docs(order-checklist): use global rs-online.com URL in header
    The RS Components header now points to the global landing page (https://www.rs-online.com) instead of the Norway-specific store, so readers worldwide get redirected to their local RS site. The LiPo deep link stays as no.rs-online.com — that SKU only resolves at the Norway store; added a note so non-Norwegian readers know to search their local RS for an equivalent.
2026-05-28 docs: fix RTC use claim + add battery polarity warning
2026-05-28 docs(case): point-value slicer settings + ship Fusion + STEP CAD source
    slicer-settings.md: exact values used on the original prints (25%
    infill, 4 walls, 4 top/bottom, supports everywhere, slicer-default
    speed) instead of vague ranges. 0.4 mm nozzle noted.
    Adds Case.f3z (Fusion 360 archive, parametric) and Case.step (neutral
    CAD interchange) under case-design/. Anyone substituting parts can
    fork the CAD directly instead of asking.
    [Case.f3z, Case.step]
